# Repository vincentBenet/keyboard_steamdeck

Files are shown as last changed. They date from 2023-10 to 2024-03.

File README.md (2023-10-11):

# keyboard_steamdeck

[Github](https://github.com/vincentBenet/keyboard_steamdeck)
[Author: Vincent Bénet](https://github.com/vincentBenet)

## Introduction

This project aim to create a minimalist custom keyboard using standard keycaps.
The goal is to have no keys restriction compare to a 120% keyboard.

## Features
Bellow a list of features of this keyboard:

    - All keys from 120% keyboards (Directionnal arrows, del, backspace, G keys)
    
    - Possibility to switch from AZERTY to QWERTY
    
    - 8 programables macro-G-keys
    
    - Up to 6 differents keys mapped on one switch (FN1, FN2, FN3, FN4, SHIFT, Simple press)
    
    - Reprogramming possibility of firmware
    
    - Electro Static Protection using TVS USB
    
    - Very low energy consumption using STM32L0 Chip
    
    - Case-material versatile (Wood, Aluminium, Inox, plastic, ...) (2mm cutted sheet)
    
## Layout
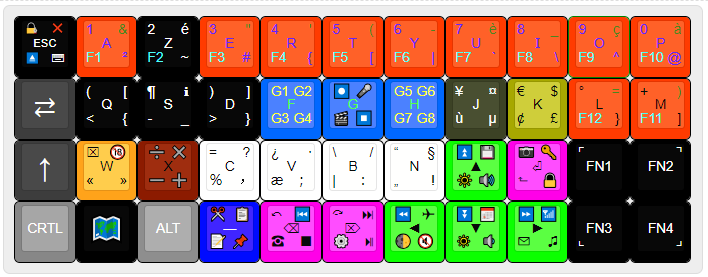
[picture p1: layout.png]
layout


[Edit - Layout](http://www.keyboard-layout-editor.com/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'%0A%7B%0A%0A%0A%0A%0A%0AR&=5%0AF5%0A(%0A%5B%0A%0A%0A%0A%0A%0AT&=6%0AF6%0A-%0A%7C%0A%0A%0A%0A%0A%0AY&=7%0AF7%0A%C3%A8%0A%60%0A%0A%0A%0A%0A%0AU&=8%0AF8%0A%2F_%0A%5C%0A%0A%0A%0A%0A%0A%E2%85%A0&=9%0AF9%0A%C3%A7%0A%5E%0A%0A%0A%0A%0A%0AO&=0%0AF10%0A%C3%A0%0A%2F@%0A%0A%0A%0A%0A%0AP%3B&@_c=%233d3d3d&t=%23ffffff&a:7&f:9%3B&=%E2%87%84&_c=%23000000&a:4&f:3%3B&=(%0A%3C%0A%5B%0A%7B%0A%0A%0A%0A%0A%0AQ&=%C2%B6%0A-%0A%E2%84%B9%EF%B8%8F%0A%2F_%0A%0A%0A%0A%0A%0AS&=)%0A%3E%0A%5D%0A%7D%0A%0A%0A%0A%0A%0AD&_c=%230068ff&t=%23fff300%0A%0A%0A%0A%0A%0A%0A%0A%0A%2300ff17%3B&=G1%0AG3%0AG2%0AG4%0A%0A%0A%0A%0A%0AF&_t=%23a32424%0A%0A%0A%23ff0000%0A%0A%0A%0A%0A%0A%2300ff17%3B&=%E2%8F%BA%0A%F0%9F%8E%AC%0A%F0%9F%8E%A4%0A%E2%8F%B9%0A%0A%0A%0A%0A%0AG&_t=%23fff300%0A%0A%0A%0A%0A%0A%0A%0A%0A%2300ff17%3B&=G5%0AG7%0AG6%0AG8%0A%0A%0A%0A%0A%0AH&_c=%233c4225&t=%23ffffff%3B&=%C2%A5%0A%C3%B9%0A%C2%A4%0A%C2%B5%0A%0A%0A%0A%0A%0AJ&_c=%23a7a800&t=%23000000%3B&=%E2%82%AC%0A%C2%A2%0A$%0A%C2%A3%0A%0A%0A%0A%0A%0AK&_c=%23ff3b00&t=%23000000%0A%2300ffde%0A%23337000%3B&=%C2%B0%0AF12%0A%2F=%0A%7D%0A%0A%0A%0A%0A%0AL&=+%0AF11%0A)%0A%5D%0A%0A%0A%0A%0A%0AM%3B&@_c=%233d3d3d&t=%23ffffff&a:7&f:9%3B&=%E2%86%91&_c=%23ffa31a&t=%23000000&a:4&f:3%3B&=%E2%8C%A7%0A%C2%AB%0A%F0%9F%94%9E%0A%C2%BB%0A%0A%0A%0A%0A%0AW&_c=%238c1b00%3B&=%E2%9E%97%0A%E2%9E%96%0A%E2%9C%96%EF%B8%8F%0A%E2%9E%95%0A%0A%0A%0A%0A%0AX&_c=%23ffffff%3B&=%2F=%0A%EF%BC%85%0A%3F%0A%EF%B9%90%0A%0A%0A%0A%0A%0AC&=%C2%BF%0A%C3%A6%0A%E2%80%A7%0A%EF%BC%9B%0A%0A%0A%0A%0A%0AV&=%5C%0A%7C%0A%2F%2F%0A%EF%BC%9A%0A%0A%0A%0A%0A%0AB&=%E2%80%9C%0A%E2%80%9E%0A%C2%A7%0A!%0A%0A%0A%0A%0A%0AN&_c=%230bff00%3B&=%E2%8F%AB%0A%F0%9F%94%86%0A%F0%9F%92%BE%0A%F0%9F%94%8A%0A%0A%0A%0A%0A%0A%E2%96%B2&_c=%23ff00e8%3B&=%F0%9F%93%B7%0A%E2%AC%91%0A%F0%9F%94%91%0A%F0%9F%94%92%0A%0A%0A%0A%0A%0A%E2%8F%8E&_c=%23000000&t=%23ffffff%3B&=%E2%8C%9C%0A%0A%0A%0A%0A%0A%0A%0A%0AFN1&=%0A%0A%E2%8C%9D%0A%0A%0A%0A%0A%0A%0AFN2%3B&@_c=%23878787&a:7%3B&=CRTL&_c=%23000000&f:9%3B&=%F0%9F%97%BA%EF%B8%8F&_c=%238e8e8e&f:3%3B&=ALT&_c=%23000bff&a:4%3B&=%E2%9C%82%EF%B8%8F%0A%F0%9F%93%9D%0A%F0%9F%93%8B%0A%F0%9F%93%8C%0A%0A%0A%0A%0A%0A%E2%80%95&_c=%23ff00e8&t=%23000000%3B&=%E2%A4%BA%0A%E2%98%8E%0A%E2%8F%AE%0A%E2%8F%B9%0A%0A%0A%0A%0A%0A%E2%8C%AB&=%E2%A4%BC%0A%E2%9A%99%EF%B8%8F%0A%E2%8F%AD%0A%E2%8F%AF%0A%0A%0A%0A%0A%0A%E2%8C%A6&_c=%230bff00%3B&=%E2%8F%AA%0A%F0%9F%8C%93%0A%E2%9C%88%0A%F0%9F%94%87%0A%0A%0A%0A%0A%0A%E2%97%84&=%E2%8F%AC%0A%F0%9F%94%85%0A%F0%9F%93%85%0A%F0%9F%94%89%0A%0A%0A%0A%0A%0A%E2%96%BC&=%E2%8F%A9%0A%E2%9C%89%0A%F0%9F%93%B6%0A%E2%99%AB%0A%0A%0A%0A%0A%0A%E2%96%BA&_c=%23000000&t=%23ffffff%3B&=%0A%E2%8C%9E%0A%0A%0A%0A%0A%0A%0A%0AFN3&=%0A%0A%0A%E2%8C%9F%0A%0A%0A%0A%0A%0AFN4)

## Model 3D
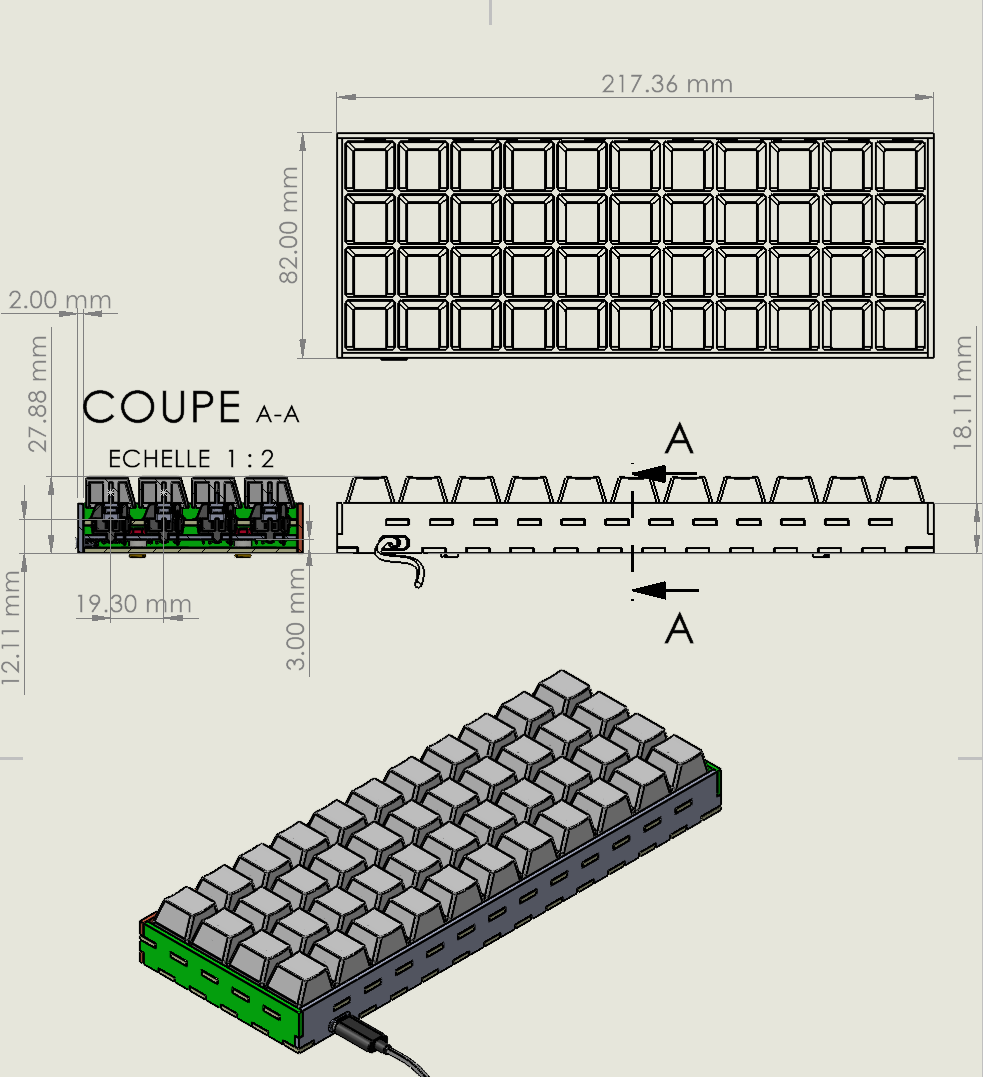
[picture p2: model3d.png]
model3d


## Schematic
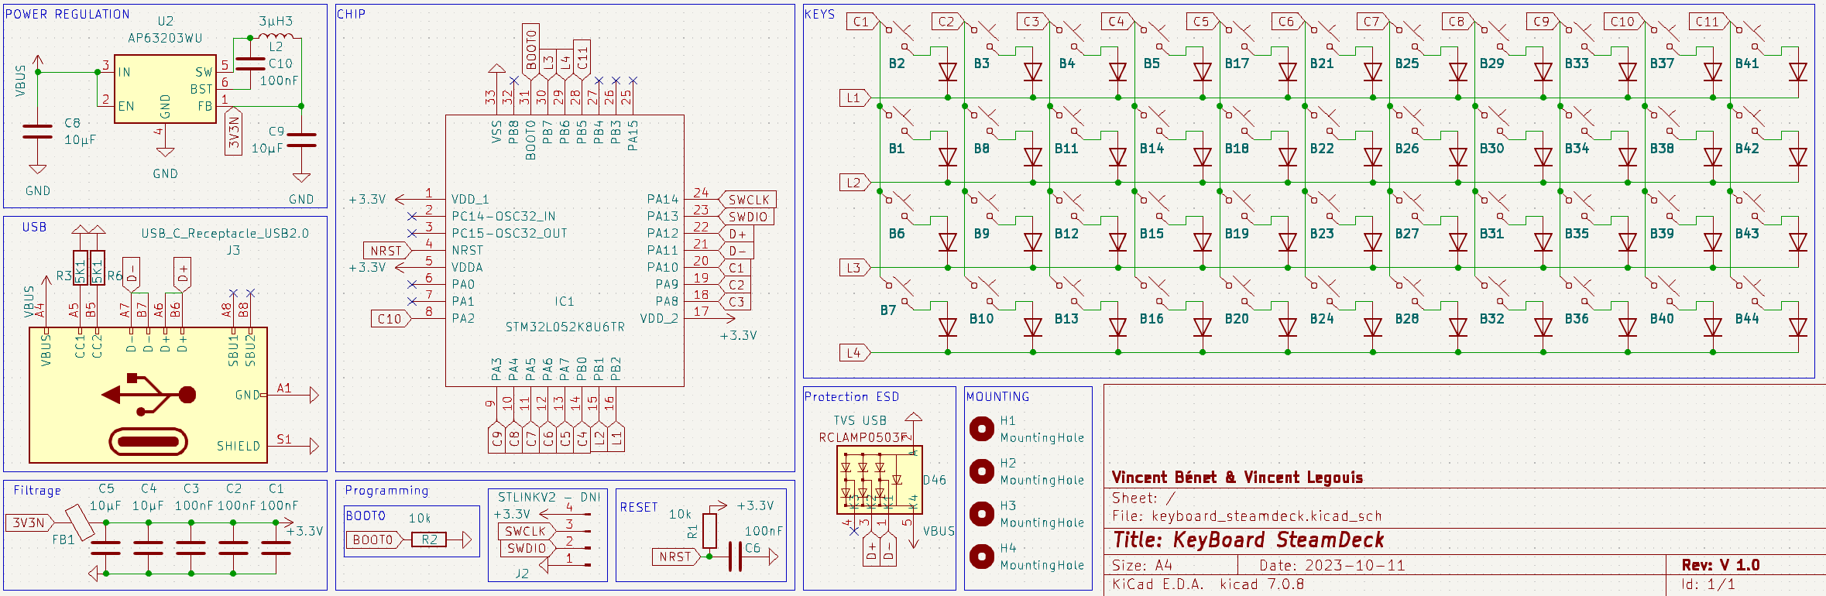
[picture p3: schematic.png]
schematic


## Routing
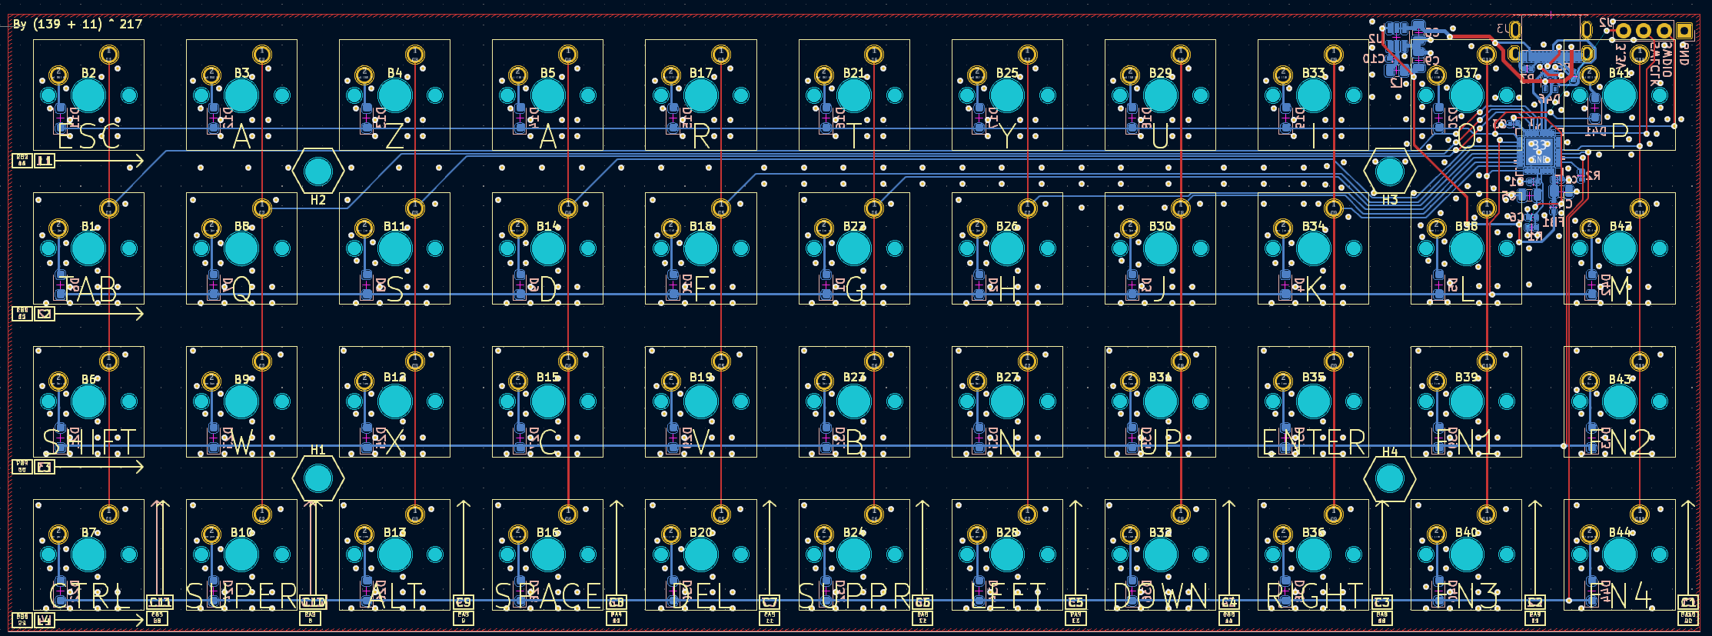
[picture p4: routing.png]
routing


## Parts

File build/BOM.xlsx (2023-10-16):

Item | Type | Domain | Name | Vendor | Price | Parameter | Quantity | URL | File
1 | Key switch | Mechatronic | Cherry MX Red | boutique-keycaps | 49.99 € | X | 47 | Cherry MX Red | Boutique Keycaps (boutique-keycaps.com) (https://boutique-keycaps.com/products/cherry-mx-red?variant=39810772959301) | X
2 | Keyboard case | Mechanic | plaque_arriere | Xometry | 147.60 € | Aluminium 2mm | 5 | https://xometry.eu/fr/ | build/plaque_arriere.DXF
3 |  |  | plaque_dessous |  |  |  | 5 |  | build/plaque_dessous.DXF
4 |  |  | plaque_frontale |  |  |  | 5 |  | build/plaque_frontale.DXF
5 |  |  | plaque_laterale |  |  |  | 10 |  | build/plaque_laterale.DXF
6 |  |  | plaque_principale |  |  |  | 5 |  | build/plaque_principale.DXF
7 | Keycaps | Mechanic | Keyboard layout |  |  |  | 1 |  | build/keyboard-layout.json (http://www.keyboard-layout-editor.com/)
8 | PCB | Electronic | PCB build | PCB ways | 213.01 € |  | 5 | https://www.pcbway.com/ | build/
9 | PCB Assembly | Electronic | PCB assembly service |  |  |  | 2 |  | X
10 | PCB componants | Electronic | Electronics componants |  |  |  | 2 |  | build/BOM_electronics.xlsx
 |  |  |  |  | 410.60 €

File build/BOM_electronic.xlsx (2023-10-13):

 |  |  | Keyboard SteamDeck - PCS BOM (Sample Bill of Materials)
Item # | *Designator | *Qty | Manufacturer | *Mfg Part # | Description / Value | *Package/Footprint | Type | Your Instructions / Notes
1 | > B1-B44 | 44 | cherrymx | MX2A-L1NN | CHERRY MX RED | X | thru-hole | Do Not Include
2 | > C1-C3, C6, C10 | 5 | YAGEO | CC0402KRX7R8BB104 | CAP CER 0.1UF 25V X7R 0402 | 402 | SMD
3 | > C4, C5, C8, C9 | 4 | Cal-Chip Electronics, Inc. | CAP0805 X7R 10UF 10% 16V | CAP CER 0.1UF 25V X7R 0402 | 805 | SMD
4 | > D1-D44 | 44 | Micro Commercial Co | 1N4148WX-TP | DIODE GEN PURP 75V 150MA SOD323 | SOD-323 | SMD
5 | D46 | 1 | Semtech Corporation | RCLAMP0503F.TCT | TVS DIODE 5VWM 25VC SC70-5 | SOT-353 | SMD
6 | FB1 | 1 | Pulse Electronics | PE-0603PFB121ST | FERRITE BEAD 600 OHM 0402 1LN | 402 | SMD
7 | > H1-H4 | 4 | X |  | M3 MOUNTING HOLE | X | thru-hole
8 | IC1 | 1 | StMicroelectronic | STM32L052K8U6TR | IC MCU 32BIT 64KB FLASH 32UFQFPN | SMD | SMD
9 | J2 | 1 | Würth Elektronik | 61300411121 | CONN HEADER VERT 4POS 2.54MM | 2.54 | thru-hole | Do Not Include
10 | J3 | 1 | Molex | 2130830005 | CONN RCP USB2.0 TYP C 24P SMD RA | Right Angle | thru-hole
11 | L2 | 1 | TDK Corporation | MLZ2012N3R3LT000 | FIXED IND 3.3UH 750MA 150MOHM SM | 805 | SMD
12 | > R1, R2 | 2 | Panasonic Electronic Components | ERA-2AEB103X | RES SMD 10K OHM 0.1% 1/16W 0402 | 402 | SMD
13 | > R3, R6 | 2 | KOA Speer Electronics, Inc. | RN73R1ETTP5101B25 | RES 5.1K OHM 0.1% 1/16W 0402 | 402 | SMD
14 | U2 | 1 | Diodes Incorporated | AP63203WU-7 | IC REG BUCK 3.3V 2A TSOT23-6 | SOT-23-6 | SMD
 |  | 62

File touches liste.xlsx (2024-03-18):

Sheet: KEYS
CODE | Name | Key | SHIFT | ALTGR | CTRL | MODIFIER | Usage key | Usage SHIFT | Usage ALTGR | Usage CTRL
01 | KEY_MOD_LCTRL | CTRL | __ | __ | __ | 1 | 5 | 0 | 0 | 0
02 | KEY_MOD_LSHIFT | SHIFT | __ | __ | __ | 1 | 5 | 0 | 0 | 0
04 | KEY_MOD_LALT | ALT | __ | __ | __ | 1 | 5 | 0 | 0 | 0
08 | KEY_MOD_LMETA | SUPER | __ | __ | __ | 1 | 5 | 0 | 0 | 0
10 | KEY_MOD_RCTRL | RCTRL | __ | __ | __ | 1 | 0 | 0 | 0 | 0
20 | KEY_MOD_RSHIFT | RSHIFT | __ | __ | __ | 1 | 0 | 0 | 0 | 0
40 | KEY_MOD_RALT | RALT | __ | __ | __ | 1 | 0 | 0 | 0 | 0
80 | KEY_MOD_RMETA | RMETA | __ | __ | __ | 1 | 0 | 0 | 0 | 0
00 | Reserved (no event indicated) | NONE | __ | __ | __ | 0 | 44 | 0 | 0 | 0
01 | Keyboard ErrorRollOver | __ | __ | __ | __ | 0 | 0 | 0 | 0 | 0
02 | Keyboard POSTFail | __ | __ | __ | __ | 0 | 0 | 0 | 0 | 0
03 | Keyboard ErrorUndefined | __ | __ | __ | __ | 0 | 0 | 0 | 0 | 0
04 | Keyboard a and A | q | __ | __ | __ | 0 | 1 | 0 | 0 | 0
05 | Keyboard b and B | b | __ | __ | __ | 0 | 1 | 0 | 0 | 0
06 | Keyboard c and C | c | __ | __ | COPY | 0 | 1 | 0 | 0 | 1
07 | Keyboard d and D | d | __ | __ | __ | 0 | 1 | 0 | 0 | 0
08 | Keyboard e and E | e | __ | € | __ | 0 | 1 | 0 | 1 | 0
09 | Keyboard f and F | f | __ | __ | FIND | 0 | 1 | 0 | 0 | 1
0A | Keyboard g and G | g | __ | __ | __ | 0 | 1 | 0 | 0 | 0
0B | Keyboard h and H | h | __ | __ | __ | 0 | 1 | 0 | 0 | 0
0C | Keyboard i and I | i | __ | __ | __ | 0 | 1 | 0 | 0 | 0
0D | Keyboard j and J | j | __ | __ | __ | 0 | 1 | 0 | 0 | 0
0E | Keyboard k and K | k | __ | __ | __ | 0 | 1 | 0 | 0 | 0
0F | Keyboard l and L | l | __ | __ | __ | 0 | 1 | 0 | 0 | 0
10 | Keyboard m and M | , | ? | __ | __ | 0 | 1 | 85 | 0 | 0
11 | Keyboard n and N | n | __ | __ | __ | 0 | 1 | 0 | 0 | 0
12 | Keyboard o and O | o | __ | __ | __ | 0 | 1 | 0 | 0 | 0
13 | Keyboard p and P | p | __ | __ | __ | 0 | 1 | 0 | 0 | 0
14 | Keyboard q and Q | a | __ | __ | __ | 0 | 1 | 0 | 0 | 0
15 | Keyboard r and R | r | __ | __ | REPLACE | 0 | 1 | 0 | 0 | 1
16 | Keyboard s and S | s | __ | __ | __ | 0 | 1 | 0 | 0 | 0
17 | Keyboard t and T | t | __ | __ | __ | 0 | 1 | 0 | 0 | 0
18 | Keyboard u and U | u | __ | __ | __ | 0 | 1 | 0 | 0 | 0
19 | Keyboard v and V | v | __ | __ | PASTE | 0 | 1 | 0 | 0 | 1
1A | Keyboard w and W | z | __ | __ | UNDO | 0 | 1 | 0 | 0 | 1
1B | Keyboard x and X | x | __ | __ | CUT | 0 | 1 | 0 | 0 | 1
1C | Keyboard y and Y | y | __ | __ | AGAIN | 0 | 1 | 0 | 0 | 1
1D | Keyboard z and Z | w | __ | __ | CLOSE | 0 | 1 | 0 | 0 | 1
1E | Keyboard 1 and ! | & | 1 | __ | __ | 0 | 2 | 1 | 0 | 0
1F | Keyboard 2 and @ | é | 2 | ~ | __ | 0 | 1 | 1 | 1 | 0
20 | Keyboard 3 and # | " | 3 | # | __ | 0 | 1 | 1 | 1 | 0
21 | Keyboard 4 and $ | ' | 4 | { | __ | 0 | 1 | 1 | 2 | 0
22 | Keyboard 5 and % | ( | 5 | [ | __ | 0 | 2 | 1 | 2 | 0
23 | Keyboard 6 and ^ | - | 6 | | | __ | 0 | 2 | 1 | 2 | 0
24 | Keyboard 7 and & | è | 7 | ` | __ | 0 | 1 | 1 | 1 | 0
25 | Keyboard 8 and * | _ | 8 | \ | __ | 0 | 2 | 1 | 2 | 0
26 | Keyboard 9 and ( | ç | 9 |  | __ | 0 | 1 | 1 | 1 | 0
27 | Keyboard 0 and ) | à | 0 | @ | __ | 0 | 1 | 1 | 1 | 0
28 | Keyboard Return (ENTER) | ENTER | __ | __ | __ | 0 | 1 | 0 | 0 | 0
29 | Keyboard ESCAPE | ESCAPE | __ | __ | __ | 0 | 1 | 0 | 0 | 0
2A | Keyboard DELETE (Backspace) | BACKSPACE | __ | __ | __ | 0 | 1 | 0 | 0 | 0
2B | Keyboard Tab | TAB | __ | __ | __ | 0 | 1 | 0 | 0 | 0
2C | Keyboard Spacebar | SPACE | __ | __ | __ | 0 | 1 | 0 | 0 | 0
2D | Keyboard - and (underscore) | ) | ° | ] | __ | 0 | 2 | 1 | 2 | 0
2E | Keyboard = and + | = | + | } | __ | 0 | 0 | 2 | 2 | 0
2F | Keyboard [ and { | ^ | ¨ | __ | __ | 0 | 2 | 1 | 0 | 0
30 | Keyboard ] and } | $ | £ | ¤ | __ | 0 | 1 | 1 | 1 | 0
31 | Keyboard \ and | | * | µ | __ | __ | 0 | 290 | 1 | 0 | 0
32 | Keyboard Non-US # and ~ | __ | __ | __ | __ | 0 | 0 | 0 | 0 | 0
33 | Keyboard ; and : | m | __ | __ | __ | 0 | 1 | 0 | 0 | 0
34 | Keyboard ‘ and “ | ù | % | __ | __ | 0 | 1 | 1 | 0 | 0
35 | Keyboard Grave Accent and Tilde | ² | __ | __ | __ | 0 | 1 | 0 | 0 | 0
36 | Keyboard, and < | ; | . | __ | __ | 0 | 1 | 1 | 0 | 0
37 | Keyboard . and > | : | / | __ | __ | 0 | 1 | 1 | 0 | 0
38 | Keyboard / and ? | ! | § | __ | __ | 0 | 1 | 1 | 0 | 0
39 | Keyboard Caps Lock | Caps Lock | __ | __ | __ | 0 | 1 | 0 | 0 | 0
3A | Keyboard F1 | F1 | __ | __ | __ | 0 | 1 | 0 | 0 | 0
3B | Keyboard F2 | F2 | __ | __ | __ | 0 | 1 | 0 | 0 | 0
3C | Keyboard F3 | F3 | __ | __ | __ | 0 | 1 | 0 | 0 | 0
3D | Keyboard F4 | F4 | __ | __ | __ | 0 | 1 | 0 | 0 | 0
3E | Keyboard F5 | F5 | __ | __ | __ | 0 | 1 | 0 | 0 | 0
3F | Keyboard F6 | F6 | __ | __ | __ | 0 | 1 | 0 | 0 | 0
40 | Keyboard F7 | F7 | __ | __ | __ | 0 | 1 | 0 | 0 | 0
41 | Keyboard F8 | F8 | __ | __ | __ | 0 | 1 | 0 | 0 | 0
42 | Keyboard F9 | F9 | __ | __ | __ | 0 | 1 | 0 | 0 | 0
43 | Keyboard F10 | F10 | __ | __ | __ | 0 | 1 | 0 | 0 | 0
44 | Keyboard F11 | F11 | __ | __ | __ | 0 | 1 | 0 | 0 | 0
45 | Keyboard F12 | F12 | __ | __ | __ | 0 | 1 | 0 | 0 | 0
46 | Keyboard PrintScreen | PRINTSCREEN | __ | __ | __ | 0 | 1 | 0 | 0 | 0
47 | Keyboard Scroll Lock | __ | __ | __ | __ | 0 | 0 | 0 | 0 | 0
48 | Keyboard Pause | PAUSE | __ | __ | __ | 0 | 1 | 0 | 0 | 0
49 | Keyboard Insert | INSERT | __ | __ | __ | 0 | 1 | 0 | 0 | 0
4A | Keyboard Home | BEGIN | __ | __ | __ | 0 | 1 | 0 | 0 | 0
4B | Keyboard PageUp | PAGE UP | __ | __ | __ | 0 | 1 | 0 | 0 | 0
4C | Keyboard Delete Forward | DELETE | __ | __ | __ | 0 | 1 | 0 | 0 | 0
4D | Keyboard End | END | __ | __ | __ | 0 | 1 | 0 | 0 | 0
4E | Keyboard PageDown | PAGE DOWN | __ | __ | __ | 0 | 1 | 0 | 0 | 0
4F | Keyboard RightArrow | RIGHT | __ | __ | __ | 0 | 1 | 0 | 0 | 0
50 | Keyboard LeftArrow | LEFT | __ | __ | __ | 0 | 1 | 0 | 0 | 0
51 | Keyboard DownArrow | DOWN | __ | __ | __ | 0 | 1 | 0 | 0 | 0
52 | Keyboard UpArrow | UP | __ | __ | __ | 0 | 1 | 0 | 0 | 0
53 | Keypad Num Lock and Clear | NUM LOCK | __ | __ | __ | 0 | 1 | 0 | 0 | 0
54 | Keypad / | __ | __ | __ | __ | 0 | 0 | 0 | 0 | 0
55 | Keypad * | __ | __ | __ | __ | 0 | 0 | 0 | 0 | 0
56 | Keypad - | __ | __ | __ | __ | 0 | 0 | 0 | 0 | 0
57 | Keypad + | __ | __ | __ | __ | 0 | 0 | 0 | 0 | 0
58 | Keypad ENTER | __ | __ | __ | __ | 0 | 0 | 0 | 0 | 0
59 | Keypad 1 and End | __ | __ | __ | __ | 0 | 0 | 0 | 0 | 0
5A | Keypad 2 and Down Arrow | __ | __ | __ | __ | 0 | 0 | 0 | 0 | 0
5B | Keypad 3 and PageDn | __ | __ | __ | __ | 0 | 0 | 0 | 0 | 0
5C | Keypad 4 and Left Arrow | __ | __ | __ | __ | 0 | 0 | 0 | 0 | 0
5D | Keypad 5 | __ | __ | __ | __ | 0 | 0 | 0 | 0 | 0
5E | Keypad 6 and Right Arrow | __ | __ | __ | __ | 0 | 0 | 0 | 0 | 0
5F | Keypad 7 and Home | __ | __ | __ | __ | 0 | 0 | 0 | 0 | 0
60 | Keypad 8 and Up Arrow | __ | __ | __ | __ | 0 | 0 | 0 | 0 | 0
61 | Keypad 9 and PageUp | __ | __ | __ | __ | 0 | 0 | 0 | 0 | 0
62 | Keypad 0 and Insert | __ | __ | __ | __ | 0 | 0 | 0 | 0 | 0
63 | Keypad . and Delete | __ | __ | __ | __ | 0 | 0 | 0 | 0 | 0
64 | Keyboard Non-US \ and | | < | > | __ | __ | 0 | 0 | 0 | 0 | 0
65 | Keyboard Application | APPS | __ | __ | __ | 0 | 1 | 0 | 0 | 0
66 | Keyboard Power | __ | __ | __ | __ | 0 | 0 | 0 | 0 | 0
67 | Keypad = | __ | __ | __ | __ | 0 | 0 | 0 | 0 | 0
68 | Keyboard F13 | __ | __ | __ | __ | 0 | 0 | 0 | 0 | 0
69 | Keyboard F14 | __ | __ | __ | __ | 0 | 0 | 0 | 0 | 0
6A | Keyboard F15 | __ | __ | __ | __ | 0 | 0 | 0 | 0 | 0
6B | Keyboard F16 | __ | __ | __ | __ | 0 | 0 | 0 | 0 | 0
6C | Keyboard F17 | __ | __ | __ | __ | 0 | 0 | 0 | 0 | 0
6D | Keyboard F18 | __ | __ | __ | __ | 0 | 0 | 0 | 0 | 0
6E | Keyboard F19 | __ | __ | __ | __ | 0 | 0 | 0 | 0 | 0
6F | Keyboard F20 | __ | __ | __ | __ | 0 | 0 | 0 | 0 | 0
70 | Keyboard F21 | __ | __ | __ | __ | 0 | 0 | 0 | 0 | 0
71 | Keyboard F22 | __ | __ | __ | __ | 0 | 0 | 0 | 0 | 0
72 | Keyboard F23 | __ | __ | __ | __ | 0 | 0 | 0 | 0 | 0
73 | Keyboard F24 | __ | __ | __ | __ | 0 | 0 | 0 | 0 | 0
74 | Keyboard Execute | __ | __ | __ | __ | 0 | 0 | 0 | 0 | 0
75 | Keyboard Help | __ | __ | __ | __ | 0 | 0 | 0 | 0 | 0
76 | Keyboard Menu | __ | __ | __ | __ | 0 | 0 | 0 | 0 | 0
77 | Keyboard Select | __ | __ | __ | __ | 0 | 0 | 0 | 0 | 0
78 | Keyboard Stop | __ | __ | __ | __ | 0 | 0 | 0 | 0 | 0
79 | Keyboard Again | __ | __ | __ | __ | 0 | 0 | 0 | 0 | 0
7A | Keyboard Undo | __ | __ | __ | __ | 0 | 0 | 0 | 0 | 0
7B | Keyboard Cut | __ | __ | __ | __ | 0 | 0 | 0 | 0 | 0
7C | Keyboard Copy | __ | __ | __ | __ | 0 | 0 | 0 | 0 | 0
7D | Keyboard Paste | __ | __ | __ | __ | 0 | 0 | 0 | 0 | 0
7E | Keyboard Find | __ | __ | __ | __ | 0 | 0 | 0 | 0 | 0
7F | Keyboard Mute | __ | __ | __ | __ | 0 | 0 | 0 | 0 | 0
80 | Keyboard Volume Up | __ | __ | __ | __ | 0 | 0 | 0 | 0 | 0
81 | Keyboard Volume Down | __ | __ | __ | __ | 0 | 0 | 0 | 0 | 0
82 | Keyboard Locking Caps Lock | __ | __ | __ | __ | 0 | 0 | 0 | 0 | 0
83 | Keyboard Locking Num Lock | __ | __ | __ | __ | 0 | 0 | 0 | 0 | 0
84 | Keyboard Locking Scroll Lock | __ | __ | __ | __ | 0 | 0 | 0 | 0 | 0
85 | Keypad Comma | __ | __ | __ | __ | 0 | 0 | 0 | 0 | 0
86 | Keypad Equal Sign | __ | __ | __ | __ | 0 | 0 | 0 | 0 | 0
87 | KEY_RO | RO | __ | __ | __ | 0 | 1 | 0 | 0 | 0
88 | KEY_KATAKANAHIRAGANA | __ | __ | __ | __ | 0 | 0 | 0 | 0 | 0
89 | KEY_YEN | __ | __ | __ | __ | 0 | 0 | 0 | 0 | 0
8A | KEY_HENKAN | __ | __ | __ | __ | 0 | 0 | 0 | 0 | 0
8B | KEY_MUHENKAN | __ | __ | __ | __ | 0 | 0 | 0 | 0 | 0
8C | KEY_KPJPCOMMA | __ | __ | __ | __ | 0 | 0 | 0 | 0 | 0
8D | Keyboard International7 | __ | __ | __ | __ | 0 | 0 | 0 | 0 | 0
8E | Keyboard International8 | __ | __ | __ | __ | 0 | 0 | 0 | 0 | 0
8F | Keyboard International9 | __ | __ | __ | __ | 0 | 0 | 0 | 0 | 0
90 | KEY_HANGEUL | __ | __ | __ | __ | 0 | 0 | 0 | 0 | 0
91 | KEY_HANJA | __ | __ | __ | __ | 0 | 0 | 0 | 0 | 0
92 | KEY_KATAKANA | __ | __ | __ | __ | 0 | 0 | 0 | 0 | 0
93 | KEY_HIRAGANA | __ | __ | __ | __ | 0 | 0 | 0 | 0 | 0
94 | KEY_ZENKAKUHANKAKU | __ | __ | __ | __ | 0 | 0 | 0 | 0 | 0
95 | Keyboard LANG6 | __ | __ | __ | __ | 0 | 0 | 0 | 0 | 0
96 | Keyboard LANG7 | __ | __ | __ | __ | 0 | 0 | 0 | 0 | 0
97 | Keyboard LANG8 | __ | __ | __ | __ | 0 | 0 | 0 | 0 | 0
98 | Keyboard LANG9 | __ | __ | __ | __ | 0 | 0 | 0 | 0 | 0
99 | Keyboard Alternate Erase | __ | __ | __ | __ | 0 | 0 | 0 | 0 | 0
9A | Keyboard SysReq/Attention | __ | __ | __ | __ | 0 | 0 | 0 | 0 | 0
9B | Keyboard Cancel | __ | __ | __ | __ | 0 | 0 | 0 | 0 | 0
9C | Keyboard Clear | __ | __ | __ | __ | 0 | 0 | 0 | 0 | 0
9D | Keyboard Prior | __ | __ | __ | __ | 0 | 0 | 0 | 0 | 0
9E | Keyboard Return | __ | __ | __ | __ | 0 | 0 | 0 | 0 | 0
9F | Keyboard Separator | __ | __ | __ | __ | 0 | 0 | 0 | 0 | 0
A0 | Keyboard Out | __ | __ | __ | __ | 0 | 0 | 0 | 0 | 0
A1 | Keyboard Oper | __ | __ | __ | __ | 0 | 0 | 0 | 0 | 0
A2 | Keyboard Clear/Again | __ | __ | __ | __ | 0 | 0 | 0 | 0 | 0
A3 | Keyboard CrSel/Props | __ | __ | __ | __ | 0 | 0 | 0 | 0 | 0
A4 | Keyboard ExSel | __ | __ | __ | __ | 0 | 0 | 0 | 0 | 0
A5 | Reserved | __ | __ | __ | __ | 0 | 0 | 0 | 0 | 0
B0 | Keypad 00 | __ | __ | __ | __ | 0 | 0 | 0 | 0 | 0
B1 | Keypad 000 | __ | __ | __ | __ | 0 | 0 | 0 | 0 | 0
B2 | Thousands Separator | __ | __ | __ | __ | 0 | 0 | 0 | 0 | 0
B3 | Decimal Separator | __ | __ | __ | __ | 0 | 0 | 0 | 0 | 0
B4 | Currency Unit | __ | __ | __ | __ | 0 | 0 | 0 | 0 | 0
B5 | Currency Sub-unit | __ | __ | __ | __ | 0 | 0 | 0 | 0 | 0
B6 | Keypad ( | __ | __ | __ | __ | 0 | 0 | 0 | 0 | 0
B7 | Keypad ) | __ | __ | __ | __ | 0 | 0 | 0 | 0 | 0
B8 | Keypad { | __ | __ | __ | __ | 0 | 0 | 0 | 0 | 0
B9 | Keypad } | __ | __ | __ | __ | 0 | 0 | 0 | 0 | 0
BA | Keypad Tab | __ | __ | __ | __ | 0 | 0 | 0 | 0 | 0
BB | Keypad Backspace | __ | __ | __ | __ | 0 | 0 | 0 | 0 | 0
BC | Keypad A | __ | __ | __ | __ | 0 | 0 | 0 | 0 | 0
BD | Keypad B | __ | __ | __ | __ | 0 | 0 | 0 | 0 | 0
BE | Keypad C | __ | __ | __ | __ | 0 | 0 | 0 | 0 | 0
BF | Keypad D | __ | __ | __ | __ | 0 | 0 | 0 | 0 | 0
C0 | Keypad E | __ | __ | __ | __ | 0 | 0 | 0 | 0 | 0
C1 | Keypad F | __ | __ | __ | __ | 0 | 0 | 0 | 0 | 0
C2 | Keypad XOR | __ | __ | __ | __ | 0 | 0 | 0 | 0 | 0
C3 | Keypad ^ | __ | __ | __ | __ | 0 | 0 | 0 | 0 | 0
C4 | Keypad % | __ | __ | __ | __ | 0 | 0 | 0 | 0 | 0
C5 | Keypad < | __ | __ | __ | __ | 0 | 0 | 0 | 0 | 0
C6 | Keypad > | __ | __ | __ | __ | 0 | 0 | 0 | 0 | 0
C7 | Keypad & | __ | __ | __ | __ | 0 | 0 | 0 | 0 | 0
C8 | Keypad && | __ | __ | __ | __ | 0 | 0 | 0 | 0 | 0
C9 | Keypad | | __ | __ | __ | __ | 0 | 0 | 0 | 0 | 0
CA | Keypad || | __ | __ | __ | __ | 0 | 0 | 0 | 0 | 0
CB | Keypad : | __ | __ | __ | __ | 0 | 0 | 0 | 0 | 0
CC | Keypad # | __ | __ | __ | __ | 0 | 0 | 0 | 0 | 0
CD | Keypad Space | __ | __ | __ | __ | 0 | 0 | 0 | 0 | 0
CE | Keypad @ | __ | __ | __ | __ | 0 | 0 | 0 | 0 | 0
CF | Keypad ! | __ | __ | __ | __ | 0 | 0 | 0 | 0 | 0
D0 | Keypad Memory Store | __ | __ | __ | __ | 0 | 0 | 0 | 0 | 0
D1 | Keypad Memory Recall | __ | __ | __ | __ | 0 | 0 | 0 | 0 | 0
D2 | Keypad Memory Clear | __ | __ | __ | __ | 0 | 0 | 0 | 0 | 0
D3 | Keypad Memory Add | __ | __ | __ | __ | 0 | 0 | 0 | 0 | 0
D4 | Keypad Memory Subtract | __ | __ | __ | __ | 0 | 0 | 0 | 0 | 0
D5 | Keypad Memory Multiply | __ | __ | __ | __ | 0 | 0 | 0 | 0 | 0
D6 | Keypad Memory Divide | __ | __ | __ | __ | 0 | 0 | 0 | 0 | 0
D7 | Keypad +/- | __ | __ | __ | __ | 0 | 0 | 0 | 0 | 0
D8 | Keypad Clear | __ | __ | __ | __ | 0 | 0 | 0 | 0 | 0
D9 | Keypad Clear Entry | __ | __ | __ | __ | 0 | 0 | 0 | 0 | 0
DA | Keypad Binary | __ | __ | __ | __ | 0 | 0 | 0 | 0 | 0
DB | Keypad Octal | __ | __ | __ | __ | 0 | 0 | 0 | 0 | 0
DC | Keypad Decimal | __ | __ | __ | __ | 0 | 0 | 0 | 0 | 0
DD | Keypad Hexadecimal | __ | __ | __ | __ | 0 | 0 | 0 | 0 | 0
DE | Reserved | __ | __ | __ | __ | 0 | 0 | 0 | 0 | 0
DF | Reserved | __ | __ | __ | __ | 0 | 0 | 0 | 0 | 0
E0 | KEY_LEFTCTRL | __ | __ | __ | __ | 0 | 0 | 0 | 0 | 0
E1 | KEY_LEFTSHIFT | __ | __ | __ | __ | 0 | 0 | 0 | 0 | 0
E2 | KEY_LEFTALT | __ | __ | __ | __ | 0 | 0 | 0 | 0 | 0
E3 | KEY_LEFTMETA | __ | __ | __ | __ | 0 | 0 | 0 | 0 | 0
E4 | KEY_RIGHTCTRL | __ | __ | __ | __ | 0 | 0 | 0 | 0 | 0
E5 | KEY_RIGHTSHIFT | __ | __ | __ | __ | 0 | 0 | 0 | 0 | 0
E6 | KEY_RIGHTALT | __ | __ | __ | __ | 0 | 0 | 0 | 0 | 0
E7 | KEY_RIGHTMETA | __ | __ | __ | __ | 0 | 0 | 0 | 0 | 0
E8 | KEY_MEDIA_PLAYPAUSE | __ | __ | __ | __ | 0 | 0 | 0 | 0 | 0
E9 | KEY_MEDIA_STOPCD | __ | __ | __ | __ | 0 | 0 | 0 | 0 | 0
EA | KEY_MEDIA_PREVIOUSSONG | __ | __ | __ | __ | 0 | 0 | 0 | 0 | 0
EB | KEY_MEDIA_NEXTSONG | __ | __ | __ | __ | 0 | 0 | 0 | 0 | 0
EC | KEY_MEDIA_EJECTCD | __ | __ | __ | __ | 0 | 0 | 0 | 0 | 0
ED | KEY_MEDIA_VOLUMEUP | __ | __ | __ | __ | 0 | 0 | 0 | 0 | 0
EE | KEY_MEDIA_VOLUMEDOWN | __ | __ | __ | __ | 0 | 0 | 0 | 0 | 0
EF | KEY_MEDIA_MUTE | __ | __ | __ | __ | 0 | 0 | 0 | 0 | 0
F0 | KEY_MEDIA_WWW | __ | __ | __ | __ | 0 | 0 | 0 | 0 | 0
F1 | KEY_MEDIA_BACK | __ | __ | __ | __ | 0 | 0 | 0 | 0 | 0
F2 | KEY_MEDIA_FORWARD | __ | __ | __ | __ | 0 | 0 | 0 | 0 | 0
F3 | KEY_MEDIA_STOP | __ | __ | __ | __ | 0 | 0 | 0 | 0 | 0
F4 | KEY_MEDIA_FIND | __ | __ | __ | __ | 0 | 0 | 0 | 0 | 0
F5 | KEY_MEDIA_SCROLLUP | __ | __ | __ | __ | 0 | 0 | 0 | 0 | 0
F6 | KEY_MEDIA_SCROLLDOWN | __ | __ | __ | __ | 0 | 0 | 0 | 0 | 0
F7 | KEY_MEDIA_EDIT | __ | __ | __ | __ | 0 | 0 | 0 | 0 | 0
F8 | KEY_MEDIA_SLEEP | __ | __ | __ | __ | 0 | 0 | 0 | 0 | 0
F9 | KEY_MEDIA_COFFEE | __ | __ | __ | __ | 0 | 0 | 0 | 0 | 0
FA | KEY_MEDIA_REFRESH | __ | __ | __ | __ | 0 | 0 | 0 | 0 | 0
FB | KEY_MEDIA_CALC | __ | __ | __ | __ | 0 | 0 | 0 | 0 | 0
FC | FN1 | FN1 | __ | __ | __ | 0 | 5 | 0 | 0 | 0
FD | FN2 | FN2 | __ | __ | __ | 0 | 5 | 0 | 0 | 0
FE | FN3 | FN3 | __ | __ | __ | 0 | 5 | 0 | 0 | 0
FF | FN4 | FN4 | __ | __ | __ | 0 | 5 | 0 | 0 | 0

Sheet: LAYERS
KEYS | c1 | c2 | c3 | c4 | c5 | c6 | c7 | c8 | c9 | c10 | c11 | INPUTKEYS | 1 | 2 | 3 | 4 | 5 | 6 | 7 | 8 | 9 | 10 | 11 | KEY-shift | 1 | 2 | 3 | 4 | 5 | 6 | 7 | 8 | 9 | 10 | 11 | Key-altgr | 1 | 2 | 3 | 4 | 5 | 6 | 7 | 8 | 9 | 10 | 11 | Key-ctrl | 1 | 2 | 3 | 4 | 5 | 6 | 7
l1 | ESCAPE | a | z | e | r | t | y | u | i | o | p | 1 | 0x29 | 0x14 | 0x1A | 0x08 | 0x15 | 0x17 | 0x1C | 0x18 | 0x0C | 0x12 | 0x13 | 1 | 0 | 0 | 0 | 0 | 0 | 0 | 0 | 0 | 0 | 0 | 0 | 1 | 0 | 0 | 0 | 0 | 0 | 0 | 0 | 0 | 0 | 0 | 0 | 1 | 0 | 0 | 0 | 0 | 0 | 0 | 0
l2 | TAB | q | s | d | f | g | h | j | k | l | m | 2 | 0x2B | 0x04 | 0x16 | 0x07 | 0x09 | 0x0A | 0x0B | 0x0D | 0x0E | 0x0F | 0x33 | 2 | 0 | 0 | 0 | 0 | 0 | 0 | 0 | 0 | 0 | 0 | 0 | 2 | 0 | 0 | 0 | 0 | 0 | 0 | 0 | 0 | 0 | 0 | 0 | 2 | 0 | 0 | 0 | 0 | 0 | 0 | 0
l3 | SHIFT | w | x | c | v | b | n | UP | ENTER | FN1 | FN2 | 3 | 0x02 | 0x1D | 0x1B | 0x06 | 0x19 | 0x05 | 0x11 | 0x52 | 0x28 | 0xFC | 0xFD | 3 | 0 | 0 | 0 | 0 | 0 | 0 | 0 | 0 | 0 | 0 | 0 | 3 | 0 | 0 | 0 | 0 | 0 | 0 | 0 | 0 | 0 | 0 | 0 | 3 | 0 | 0 | 0 | 0 | 0 | 0 | 0
l4 | CTRL | SUPER | ALT | BACKSPACE | SPACE | DELETE | LEFT | DOWN | RIGHT | FN3 | FN4 | 4 | 0x01 | 0x08 | 0x04 | 0x2A | 0x2C | 0x4C | 0x50 | 0x51 | 0x4F | 0xFE | 0xFF | 4 | 0 | 0 | 0 | 0 | 0 | 0 | 0 | 0 | 0 | 0 | 0 | 4 | 0 | 0 | 0 | 0 | 0 | 0 | 0 | 0 | 0 | 0 | 0 | 4 | 0 | 0 | 0 | 0 | 0 | 0 | 0
FN1_ | c1 | c2 | c3 | c4 | c5 | c6 | c7 | c8 | c9 | c10 | c11 | FN1KEYS | 1 | 2 | 3 | 4 | 5 | 6 | 7 | 8 | 9 | 10 | 11 | FN1-shift | 1 | 2 | 3 | 4 | 5 | 6 | 7 | 8 | 9 | 10 | 11 | FN1-altgr | 1 | 2 | 3 | 4 | 5 | 6 | 7 | 8 | 9 | 10 | 11 | FN1-ctrl | 1 | 2 | 3 | 4 | 5 | 6 | 7
l1 | NONE | & | é | " | ' | ( | - | è | _ | ç | à | 1 | 0x00 | 0x1E | 0x1F | 0x20 | 0x21 | 0x22 | 0x23 | 0x24 | 0x25 | 0x26 | 0x27 | 1 | 0 | 0 | 0 | 0 | 0 | 0 | 0 | 0 | 0 | 0 | 0 | 1 | 0 | 0 | 0 | 0 | 0 | 0 | 0 | 0 | 0 | 0 | 0 | 1 | 0 | 0 | 0 | 0 | 0 | 0 | 0
l2 | CAPS LOCK | ( | ^ | ) | , | ; | ? | ù | NONE | ) | = | 2 | 0x39 | 0x22 | 0x2F | 0x2D | 0x10 | 0x36 | 0x10 | 0x34 | 0x00 | 0x2D | 0x2E | 2 | 0 | 0 | 0 | 0 | 0 | 0 | 1 | 0 | 0 | 0 | 0 | 2 | 0 | 0 | 0 | 0 | 0 | 0 | 0 | 0 | 0 | 0 | 0 | 2 | 0 | 0 | 0 | 0 | 0 | 0 | 0
l3 | SHIFT | { | ¨ | } | . | : | ! | COPY | PASTE | FN1 | FN2 | 3 | 0x02 | 0x21 | 0x2F | 0x2E | 0x36 | 0x37 | 0x38 | 0x06 | 0x19 | 0xFC | 0xFD | 3 | 0 | 0 | 1 | 0 | 1 | 0 | 0 | 0 | 0 | 0 | 0 | 3 | 0 | 1 | 0 | 1 | 0 | 0 | 0 | 0 | 0 | 0 | 0 | 3 | 0 | 0 | 0 | 0 | 0 | 0 | 0
l4 | CTRL | SUPER | ALT | NONE | PAUSE | NONE | NONE | CUT | PRINTSCREEN | FN3 | FN4 | 4 | 0x01 | 0x08 | 0x04 | 0x00 | 0x48 | 0x00 | 0x00 | 0x1B | 0x46 | 0xFE | 0xFF | 4 | 0 | 0 | 0 | 0 | 0 | 0 | 0 | 0 | 0 | 0 | 0 | 4 | 0 | 0 | 0 | 0 | 0 | 0 | 0 | 0 | 0 | 0 | 0 | 4 | 0 | 0 | 0 | 0 | 0 | 0 | 0
FN2_ | c1 | c2 | c3 | c4 | c5 | c6 | c7 | c8 | c9 | c10 | c11 | FN2KEYS | 1 | 2 | 3 | 4 | 5 | 6 | 7 | 8 | 9 | 10 | 11 | FN2-shift | 1 | 2 | 3 | 4 | 5 | 6 | 7 | 8 | 9 | 10 | 11 | FN2-altgr | 1 | 2 | 3 | 4 | 5 | 6 | 7 | 8 | 9 | 10 | 11 | FN2-ctrl | 1 | 2 | 3 | 4 | 5 | 6 | 7
l1 | NONE | 1 | 2 | 3 | 4 | 5 | 6 | 7 | 8 | 9 | 0 | 1 | 0x00 | 0x1E | 0x1F | 0x20 | 0x21 | 0x22 | 0x23 | 0x24 | 0x25 | 0x26 | 0x27 | 1 | 0 | 1 | 1 | 1 | 1 | 1 | 1 | 1 | 1 | 1 | 1 | 1 | 0 | 0 | 0 | 0 | 0 | 0 | 0 | 0 | 0 | 0 | 0 | 1 | 0 | 0 | 0 | 0 | 0 | 0 | 0
l2 | NUM LOCK | < | / | > | - | = | + | * | % | ° | + | 2 | 0x53 | 0x64 | 0x37 | 0x64 | 0x23 | 0x2E | 0x2E | 0x31 | 0x34 | 0x2D | 0x2E | 2 | 0 | 0 | 1 | 1 | 0 | 0 | 1 | 0 | 1 | 1 | 1 | 2 | 0 | 0 | 0 | 0 | 0 | 0 | 0 | 0 | 0 | 0 | 0 | 2 | 0 | 0 | 0 | 0 | 0 | 0 | 0
l3 | SHIFT | [ | \ | ] | & | | | _ | FIND | NONE | FN1 | FN2 | 3 | 0x02 | 0x22 | 0x25 | 0x2D | 0x1E | 0x23 | 0x25 | 0x09 | 0x00 | 0xFC | 0xFD | 3 | 0 | 0 | 0 | 0 | 0 | 0 | 0 | 0 | 0 | 0 | 0 | 3 | 0 | 1 | 1 | 1 | 0 | 1 | 0 | 0 | 0 | 0 | 0 | 3 | 0 | 0 | 0 | 0 | 0 | 0 | 0
l4 | CTRL | SUPER | ALT | NONE | NONE | CLOSE | UNDO | REPLACE | AGAIN | FN3 | FN4 | 4 | 0x01 | 0x08 | 0x04 | 0x00 | 0x00 | 0x1D | 0x1A | 0x15 | 0x1C | 0xFE | 0xFF | 4 | 0 | 0 | 0 | 0 | 0 | 0 | 0 | 0 | 0 | 0 | 0 | 4 | 0 | 0 | 0 | 0 | 0 | 0 | 0 | 0 | 0 | 0 | 0 | 4 | 0 | 0 | 0 | 0 | 0 | 1 | 1
FN3_ | c1 | c2 | c3 | c4 | c5 | c6 | c7 | c8 | c9 | c10 | c11 | FN3KEYS | 1 | 2 | 3 | 4 | 5 | 6 | 7 | 8 | 9 | 10 | 11 | FN3-shift | 1 | 2 | 3 | 4 | 5 | 6 | 7 | 8 | 9 | 10 | 11 | FN3-altgr | 1 | 2 | 3 | 4 | 5 | 6 | 7 | 8 | 9 | 10 | 11 | FN3-ctrl | 1 | 2 | 3 | 4 | 5 | 6 | 7
l1 | NONE | F1 | F2 | F3 | F4 | F5 | F6 | F7 | F8 | F9 | F10 | 1 | 0x00 | 0x3A | 0x3B | 0x3C | 0x3D | 0x3E | 0x3F | 0x40 | 0x41 | 0x42 | 0x43 | 1 | 0 | 0 | 0 | 0 | 0 | 0 | 0 | 0 | 0 | 0 | 0 | 1 | 0 | 0 | 0 | 0 | 0 | 0 | 0 | 0 | 0 | 0 | 0 | 1 | 0 | 0 | 0 | 0 | 0 | 0 | 0
l2 | INSERT | NONE | NONE | NONE | NONE | NONE | NONE | NONE | NONE | F11 | F12 | 2 | 0x49 | 0x00 | 0x00 | 0x00 | 0x00 | 0x00 | 0x00 | 0x00 | 0x00 | 0x44 | 0x45 | 2 | 0 | 0 | 0 | 0 | 0 | 0 | 0 | 0 | 0 | 0 | 0 | 2 | 0 | 0 | 0 | 0 | 0 | 0 | 0 | 0 | 0 | 0 | 0 | 2 | 0 | 0 | 0 | 0 | 0 | 0 | 0
l3 | SHIFT | NONE | NONE | NONE | NONE | NONE | NONE | NONE | NONE | FN1 | FN2 | 3 | 0x02 | 0x00 | 0x00 | 0x00 | 0x00 | 0x00 | 0x00 | 0x00 | 0x00 | 0xFC | 0xFD | 3 | 0 | 0 | 0 | 0 | 0 | 0 | 0 | 0 | 0 | 0 | 0 | 3 | 0 | 0 | 0 | 0 | 0 | 0 | 0 | 0 | 0 | 0 | 0 | 3 | 0 | 0 | 0 | 0 | 0 | 0 | 0
l4 | CTRL | SUPER | ALT | NONE | NONE | NONE | NONE | NONE | NONE | FN3 | FN4 | 4 | 0x01 | 0x08 | 0x04 | 0x00 | 0x00 | 0x00 | 0x00 | 0x00 | 0x00 | 0xFE | 0xFF | 4 | 0 | 0 | 0 | 0 | 0 | 0 | 0 | 0 | 0 | 0 | 0 | 4 | 0 | 0 | 0 | 0 | 0 | 0 | 0 | 0 | 0 | 0 | 0 | 4 | 0 | 0 | 0 | 0 | 0 | 0 | 0
FN4_ | c1 | c2 | c3 | c4 | c5 | c6 | c7 | c8 | c9 | c10 | c11 | FN4KEYS | 1 | 2 | 3 | 4 | 5 | 6 | 7 | 8 | 9 | 10 | 11 | FN4-shift | 1 | 2 | 3 | 4 | 5 | 6 | 7 | 8 | 9 | 10 | 11 | FN4-altgr | 1 | 2 | 3 | 4 | 5 | 6 | 7 | 8 | 9 | 10 | 11 | FN4-ctrl | 1 | 2 | 3 | 4 | 5 | 6 | 7
l1 | NONE | ² | ~ | # | { | [ | | | ` | \ | ^ | @ | 1 | 0x00 | 0x35 | 0x1F | 0x20 | 0x21 | 0x22 | 0x23 | 0x24 | 0x25 | 0x2F | 0x27 | 1 | 0 | 0 | 0 | 0 | 0 | 0 | 0 | 0 | 0 | 0 | 0 | 1 | 0 | 0 | 1 | 1 | 1 | 1 | 1 | 1 | 1 | 0 | 1 | 1 | 0 | 0 | 0 | 0 | 0 | 0 | 0
l2 | NONE | NONE | NONE | NONE | $ | € | § | £ | ¤ | ] | } | 2 | 0x00 | 0x00 | 0x00 | 0x00 | 0x30 | 0x08 | 0x38 | 0x30 | 0x30 | 0x2D | 0x2E | 2 | 0 | 0 | 0 | 0 | 0 | 0 | 1 | 1 | 0 | 0 | 0 | 2 | 0 | 0 | 0 | 0 | 0 | 1 | 0 | 0 | 1 | 1 | 1 | 2 | 0 | 0 | 0 | 0 | 0 | 0 | 0
l3 | SHIFT | NONE | NONE | NONE | NONE | RO | µ | PAGE UP | APPS | FN1 | FN2 | 3 | 0x02 | 0x00 | 0x00 | 0x00 | 0x00 | 0x87 | 0x31 | 0x4B | 0x65 | 0xFC | 0xFD | 3 | 0 | 0 | 0 | 0 | 0 | 0 | 1 | 0 | 0 | 0 | 0 | 3 | 0 | 0 | 0 | 0 | 0 | 0 | 0 | 0 | 0 | 0 | 0 | 3 | 0 | 0 | 0 | 0 | 0 | 0 | 0
l4 | CTRL | SUPER | ALT | NONE | NONE | NONE | BEGIN | PAGE DOWN | END | FN3 | FN4 | 4 | 0x01 | 0x08 | 0x04 | 0x00 | 0x00 | 0x00 | 0x4A | 0x4E | 0x4D | 0xFE | 0xFF | 4 | 0 | 0 | 0 | 0 | 0 | 0 | 0 | 0 | 0 | 0 | 0 | 4 | 0 | 0 | 0 | 0 | 0 | 0 | 0 | 0 | 0 | 0 | 0 | 4 | 0 | 0 | 0 | 0 | 0 | 0 | 0

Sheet: OUTPUT
INPUTKEYS | 1 | 2 | 3 | 4 | 5 | 6 | 7 | 8 | 9 | 10 | 11
1 | 0x29, | 0x14, | 0x1A, | 0x08, | 0x15, | 0x17, | 0x1C, | 0x18, | 0x0C, | 0x12, | 0x13,
2 | 0x2B, | 0x04, | 0x16, | 0x07, | 0x09, | 0x0A, | 0x0B, | 0x0D, | 0x0E, | 0x0F, | 0x33,
3 | 0x02, | 0x1D, | 0x1B, | 0x06, | 0x19, | 0x05, | 0x11, | 0x52, | 0x28, | 0xFC, | 0xFD,
4 | 0x01, | 0x08, | 0x04, | 0x2A, | 0x2C, | 0x4C, | 0x50, | 0x51, | 0x4F, | 0xFE, | 0xFF
FN1KEYS | 1 | 2 | 3 | 4 | 5 | 6 | 7 | 8 | 9 | 10 | 11
1 | 0x00, | 0x1E, | 0x1F, | 0x20, | 0x21, | 0x22, | 0x23, | 0x24, | 0x25, | 0x26, | 0x27,
2 | 0x39, | 0x22, | 0x2F, | 0x2D, | 0x10, | 0x36, | 0x10, | 0x34, | 0x00, | 0x2D, | 0x2E,
3 | 0x02, | 0x21, | 0x2F, | 0x2E, | 0x36, | 0x37, | 0x38, | 0x06, | 0x19, | 0xFC, | 0xFD,
4 | 0x01, | 0x08, | 0x04, | 0x00, | 0x48, | 0x00, | 0x00, | 0x1B, | 0x46, | 0xFE, | 0xFF
FN2KEYS | 1 | 2 | 3 | 4 | 5 | 6 | 7 | 8 | 9 | 10 | 11
1 | 0x00, | 0x1E, | 0x1F, | 0x20, | 0x21, | 0x22, | 0x23, | 0x24, | 0x25, | 0x26, | 0x27,
2 | 0x53, | 0x64, | 0x37, | 0x64, | 0x23, | 0x2E, | 0x2E, | 0x31, | 0x34, | 0x2D, | 0x2E,
3 | 0x02, | 0x22, | 0x25, | 0x2D, | 0x1E, | 0x23, | 0x25, | 0x09, | 0x00, | 0xFC, | 0xFD,
4 | 0x01, | 0x08, | 0x04, | 0x00, | 0x00, | 0x1D, | 0x1A, | 0x15, | 0x1C, | 0xFE, | 0xFF
FN3KEYS | 1 | 2 | 3 | 4 | 5 | 6 | 7 | 8 | 9 | 10 | 11
1 | 0x00, | 0x3A, | 0x3B, | 0x3C, | 0x3D, | 0x3E, | 0x3F, | 0x40, | 0x41, | 0x42, | 0x43,
2 | 0x49, | 0x00, | 0x00, | 0x00, | 0x00, | 0x00, | 0x00, | 0x00, | 0x00, | 0x44, | 0x45,
3 | 0x02, | 0x00, | 0x00, | 0x00, | 0x00, | 0x00, | 0x00, | 0x00, | 0x00, | 0xFC, | 0xFD,
4 | 0x01, | 0x08, | 0x04, | 0x00, | 0x00, | 0x00, | 0x00, | 0x00, | 0x00, | 0xFE, | 0xFF
FN4KEYS | 1 | 2 | 3 | 4 | 5 | 6 | 7 | 8 | 9 | 10 | 11
1 | 0x00, | 0x35, | 0x1F, | 0x20, | 0x21, | 0x22, | 0x23, | 0x24, | 0x25, | 0x2F, | 0x27,
2 | 0x00, | 0x00, | 0x00, | 0x00, | 0x30, | 0x08, | 0x38, | 0x30, | 0x30, | 0x2D, | 0x2E,
3 | 0x02, | 0x00, | 0x00, | 0x00, | 0x00, | 0x87, | 0x31, | 0x4B, | 0x65, | 0xFC, | 0xFD,
4 | 0x01, | 0x08, | 0x04, | 0x00, | 0x00, | 0x00, | 0x4A, | 0x4E, | 0x4D, | 0xFE, | 0xFF
MODIFIER_MASK | 1 | 2 | 3 | 4 | 5 | 6 | 7 | 8 | 9 | 10 | 11
1 | 0, | 0, | 0, | 0, | 0, | 0, | 0, | 0, | 0, | 0, | 0,
2 | 0, | 0, | 0, | 0, | 0, | 0, | 0, | 0, | 0, | 0, | 0,
3 | 1, | 0, | 0, | 0, | 0, | 0, | 0, | 0, | 0, | 0, | 0,
4 | 1, | 1, | 1, | 0, | 0, | 0, | 0, | 0, | 0, | 0, | 0
TRIGGERS_MODIFIER | 1 | 2 | 3 | 4 | 5 | 6 | 7 | 8 | 9 | 10 | 11
1 | 0, | 4, | 132, | 132, | 132, | 132, | 132, | 132, | 132, | 4, | 132,
2 | 0, | 0, | 4, | 4, | 0, | 128, | 69, | 64, | 132, | 132, | 132,
3 | 0, | 10, | 9, | 10, | 1, | 8, | 64, | 6144, | 2048, | 0, | 0,
4 | 0, | 0, | 0, | 0, | 0, | 4096, | 4096, | 6144, | 4096, | 0, | 0
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

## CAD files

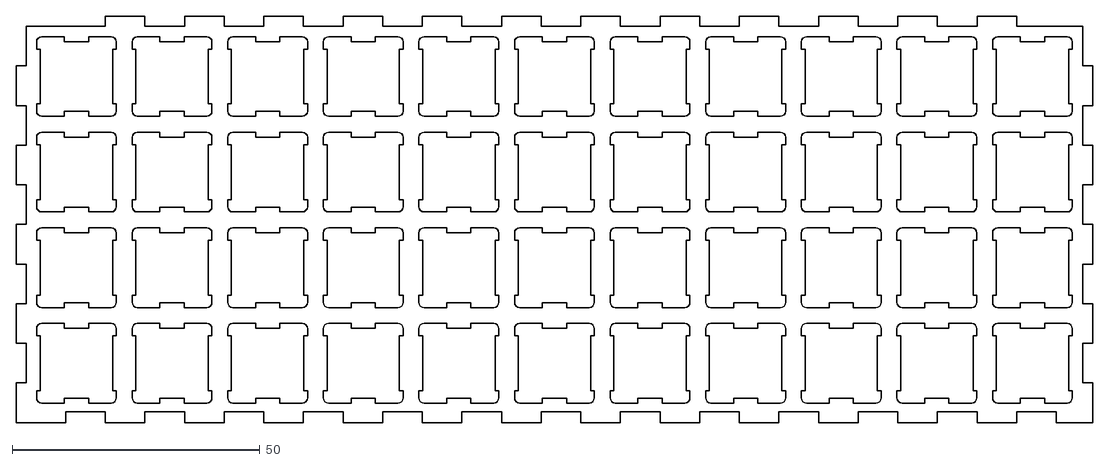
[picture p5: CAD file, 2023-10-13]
build/plaque_principale.DXF
217.4 x 82.0

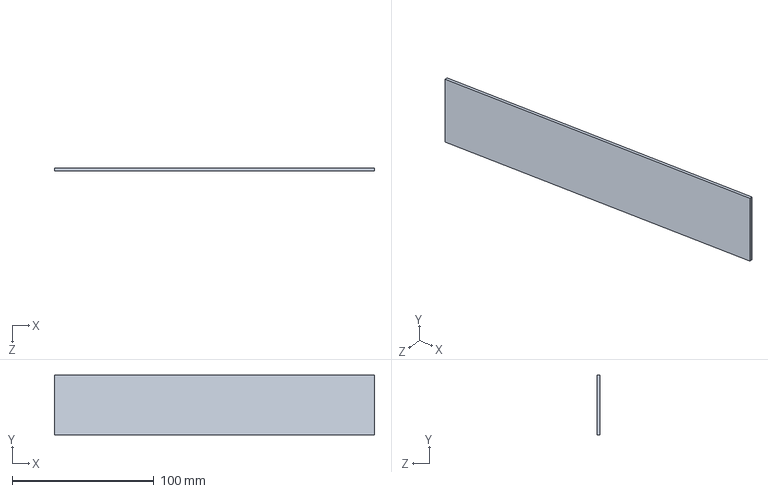
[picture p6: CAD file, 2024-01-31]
meca/plaque_frontale.SLDPRT
225.8 x 42.3 x 2.00 mm

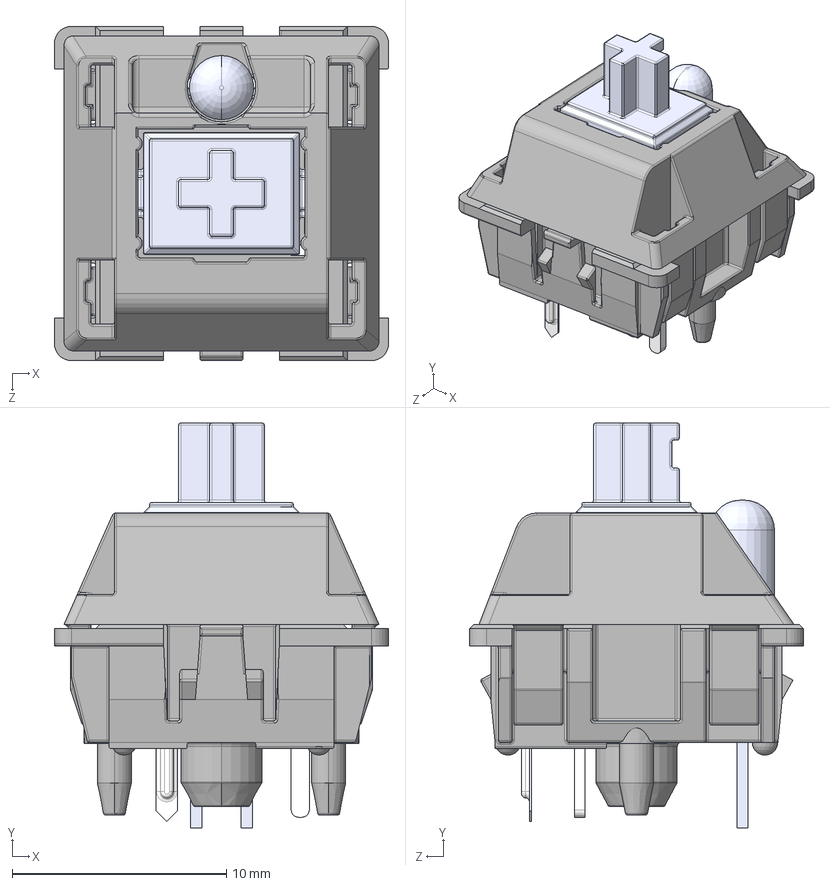
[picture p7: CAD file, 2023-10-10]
MX .STEP
15.6 x 18.9 x 15.6 mm
MX 轴 按键′_ü___¨1
MX 轴 轴体áì_¨￠¨__
MX粣 拸簽LEDLEDLED
MX轴 轴体 底部 μ×2__默认_á2____è_
针脚___默认__è_

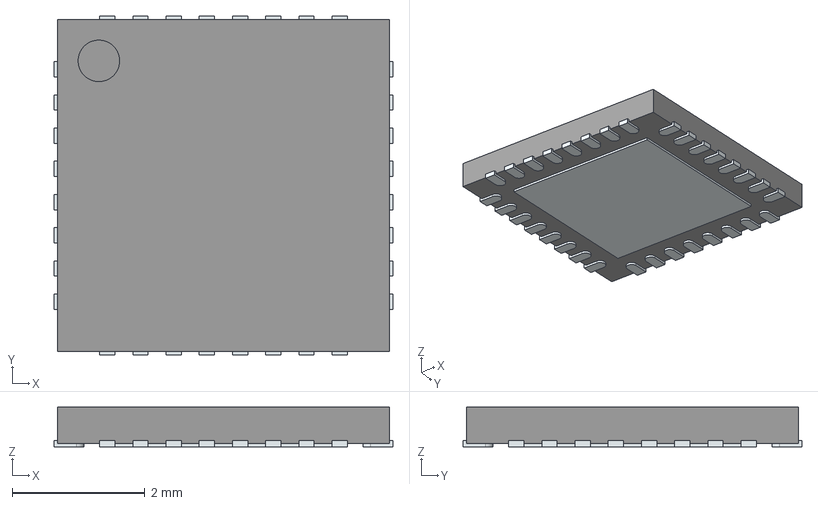
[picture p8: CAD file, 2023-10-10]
STM32L052K8U6TR/3D/STM32L052K8U6TR.stp
5.10 x 5.10 x 0.6 mm
ThermalPin
PinsArrayLR
PinsArrayTB

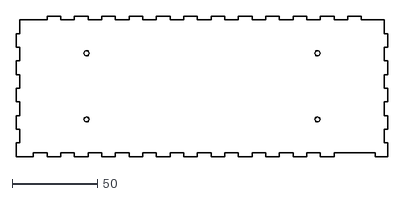
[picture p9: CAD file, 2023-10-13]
build/plaque_dessous.DXF
217.4 x 82.0

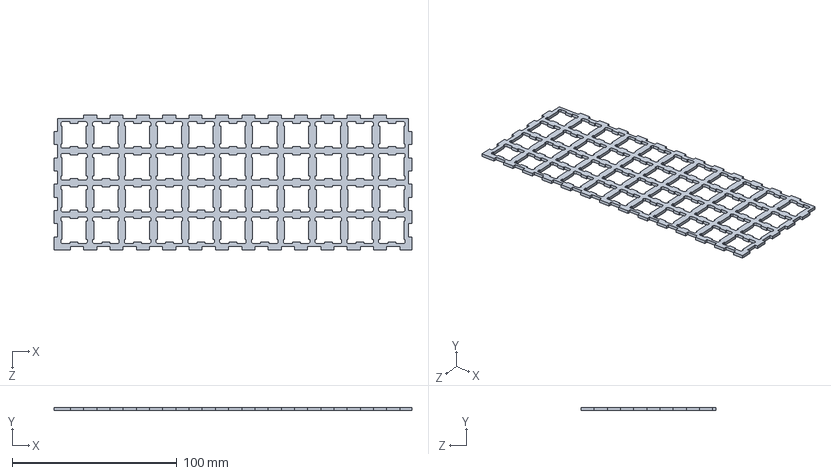
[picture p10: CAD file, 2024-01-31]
meca/plaque_principale.SLDPRT
217.4 x 2.00 x 82.0 mm

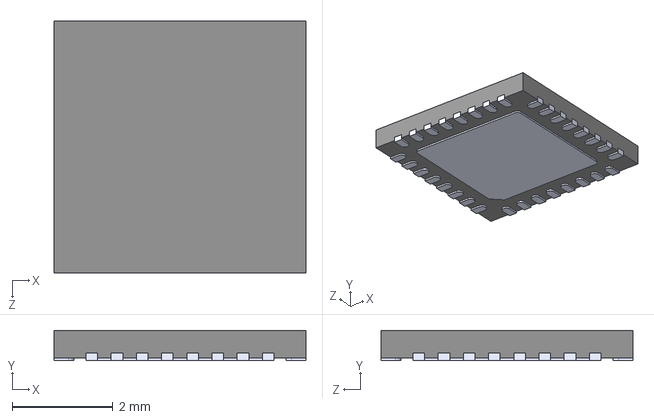
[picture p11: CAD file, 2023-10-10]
STM32L052K8U6TR.STEP
5.00 x 0.6 x 5.00 mm

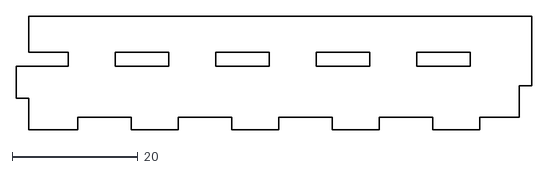
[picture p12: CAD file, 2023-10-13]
build/plaque_laterale.DXF
82.0 x 18.1

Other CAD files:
meca/MX.step.SLDASM
meca/SOT-353_SC-70-5.step.SLDASM
meca/R_0402_1005Metric.step.SLDASM
meca/C_0402_1005Metric.step.SLDASM
meca/TSOT-23-6.step.SLDASM
meca/mxcap.step.SLDASM
meca/C_0805_2012Metric.step.SLDASM
meca/D_SOD-323.step.SLDASM
meca/R_0805_2012Metric.step.SLDASM
meca/PinHeader_1x04_P2.54mm_Vertical.step.SLDASM
2130830005.stp
build/plaque_arriere.DXF
build/plaque_frontale.DXF
meca/2130830005.step.SLDASM
meca/COMPOUND-2.step.SLDPRT
meca/M3x10.SLDPRT
meca/USB-C and flexed cable.step
meca/ecrou_M3.SLDPRT
meca/entretoise.SLDPRT
meca/keyboard_steamdeck PCB.step.SLDPRT
meca/plaque_arriere.DXF
meca/plaque_arriere.SLDPRT
meca/plaque_frontale.DXF
meca/plaque_laterale.DXF
meca/plaque_laterale.SLDPRT
meca/plaque_principale.DXF
meca/plaque_principale_pleine.DXF
meca/separator.SLDPRT
mxcap.STEP

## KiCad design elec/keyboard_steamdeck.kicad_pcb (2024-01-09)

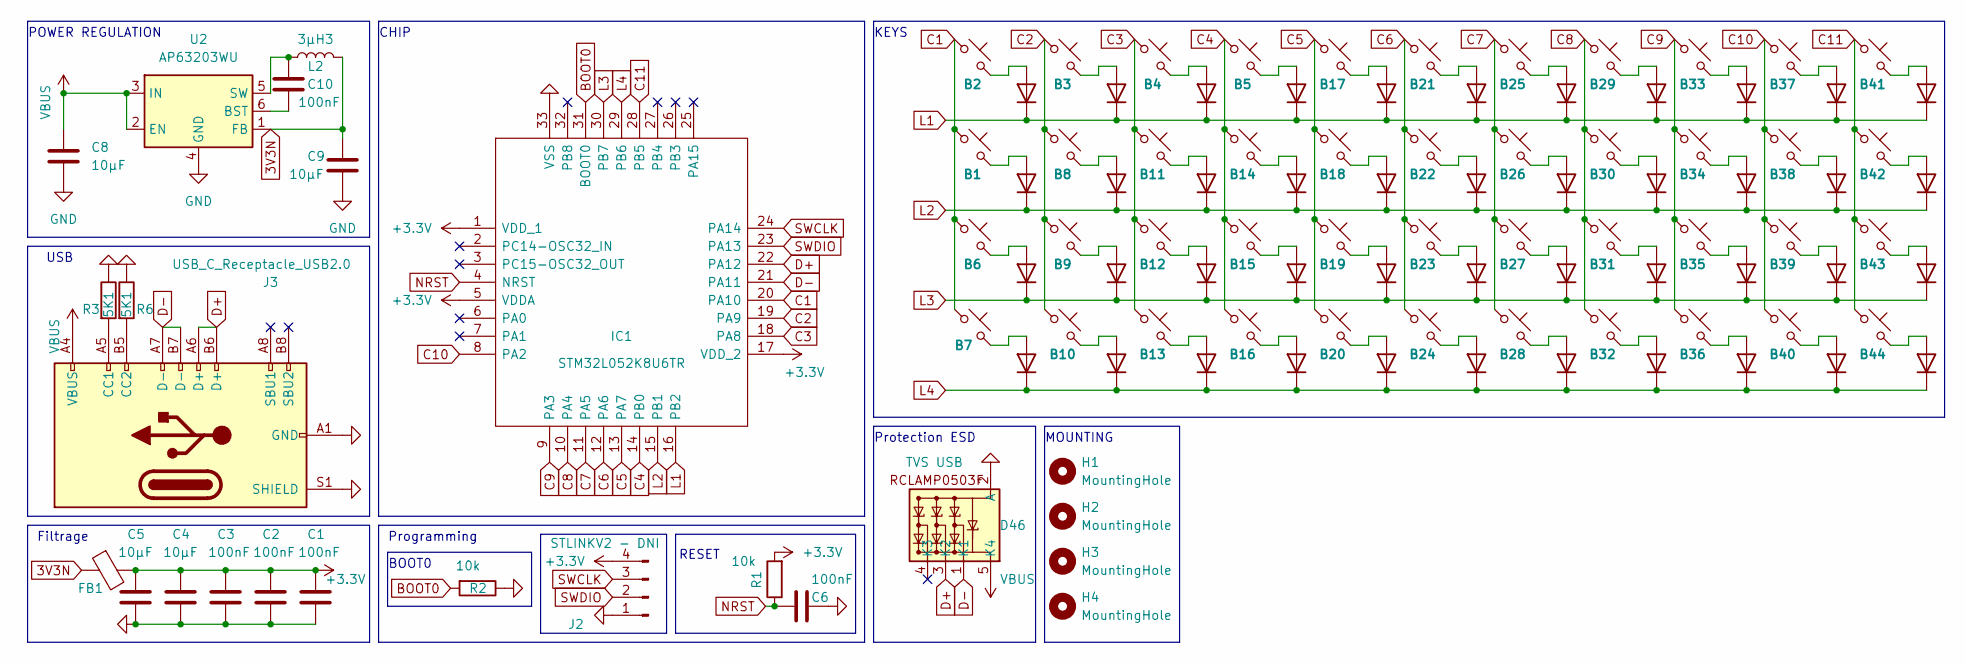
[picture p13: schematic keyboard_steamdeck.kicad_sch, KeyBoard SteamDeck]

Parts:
B1, B2, B3, B4, B5, B6, B7, B8, B9, B10, B11, B12, B13, B14, B15, B16, B17, B18, B19, B20, B21, B22, B23, B24, B25, B26, B27, B28, B29, B30, B31, B32, B33, B34, B35, B36, B37, B38, B39, B40, B41, B42, B43, B44: MX_SW_solder - DNI; SW_Cherry_MX_1.00u_PCB; MPN MX2A-L1NN
C1, C2, C3, C6, C10: 100nF; C_0402_1005Metric; MPN CC0402KRX7R8BB104
C4, C5, C8, C9: 10µF; C_0805_2012Metric; MPN CAP0805 X7R 10UF 10% 16V
D1, D2, D3, D4, D5, D6, D7, D8, D9, D10, D11, D12, D13, D14, D15, D16, D17, D18, D19, D20, D21, D22, D23, D24, D25, D26, D27, D28, D29, D30, D31, D32, D33, D34, D35, D36, D37, D38, D39, D40, D41, D42, D43, D44: 1N4148WX-TP; D_SOD-323_HandSoldering; MPN 1N4148WX-TP
D46: TVS USB; SOT-353_SC-70-5; MPN RCLAMP0503F.TCT
FB1: FerriteBead; R_0402_1005Metric; MPN PE-0603PFB121ST
H1, H2, H3, H4: MountingHole; MountingHole_3.2mm_M3
IC1: STM32L052K8U6TR; UFQFPN32-5x5mm; MPN STM32L052K8U6TR
J2: STLINKV2 - DNI; PinHeader_1x04_P2.54mm_Vertical; MPN 61300411121
J3: USB_C_Receptacle_USB2.0; USB C 2130830005; MPN 2130830005
L2: 3µH3; R_0805_2012Metric; MPN MLZ2012N3R3LT000
R1, R2: 10k; R_0402_1005Metric; MPN ERA-2AEB103X
R3, R6: 5K1; R_0402_1005Metric; MPN RN73R1ETTP5101B25
U2: AP63203WU; TSOT-23-6; MPN AP63203WU-7

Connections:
3V3N: C9.1, FB1.1, L2.2, U2.1 (FB)
+3.3V: C1.2, C2.2, C3.2, C4.2, C5.2, FB1.2, IC1.1 (VDD_1), IC1.5 (VDDA), IC1.17 (VDD_2), J2.4, R1.2
BOOT0: IC1.31 (BOOT0), R2.2
C1: B1.1, B2.1, B6.1, B7.1, IC1.20 (PA10)
C2: B3.1, B8.1, B9.1, B10.1, IC1.19 (PA9)
C3: B4.1, B11.1, B12.1, B13.1, IC1.18 (PA8)
C4: B5.1, B14.1, B15.1, B16.1, IC1.14 (PB0)
C5: B17.1, B18.1, B19.1, B20.1, IC1.13 (PA7)
C6: B21.1, B22.1, B23.1, B24.1, IC1.12 (PA6)
C7: B25.1, B26.1, B27.1, B28.1, IC1.11 (PA5)
C8: B29.1, B30.1, B31.1, B32.1, IC1.10 (PA4)
C9: B33.1, B34.1, B35.1, B36.1, IC1.9 (PA3)
C10: B37.1, B38.1, B39.1, B40.1, IC1.8 (PA2)
C11: B41.1, B42.1, B43.1, B44.1, IC1.28 (PB5)
D+: D46.3 (K2), IC1.22 (PA12), J3.A6 (D+), J3.B6 (D+)
D-: D46.1 (K1), IC1.21 (PA11), J3.A7 (D-), J3.B7 (D-)
GND: C1.1, C2.1, C3.1, C4.1, C5.1, C6.1, C8.2, C9.2, D46.2 (A), IC1.33 (VSS), J2.1, J3.A1 (GND), J3.A12 (GND), J3.B1 (GND), J3.B12 (GND), J3.S1 (SHIELD), R2.1, R3.1, R6.1, U2.4 (GND)
L1: D11.1 (K), D12.1 (K), D13.1 (K), D14.1 (K), D15.1 (K), D16.1 (K), D17.1 (K), D18.1 (K), D19.1 (K), D20.1 (K), D41.1 (K), IC1.16 (PB2)
L2: D1.1 (K), D2.1 (K), D3.1 (K), D4.1 (K), D5.1 (K), D6.1 (K), D7.1 (K), D8.1 (K), D9.1 (K), D10.1 (K), D42.1 (K), IC1.15 (PB1)
L3: D21.1 (K), D23.1 (K), D25.1 (K), D27.1 (K), D29.1 (K), D31.1 (K), D33.1 (K), D35.1 (K), D37.1 (K), D39.1 (K), D43.1 (K), IC1.30 (PB7)
L4: D22.1 (K), D24.1 (K), D26.1 (K), D28.1 (K), D30.1 (K), D32.1 (K), D34.1 (K), D36.1 (K), D38.1 (K), D40.1 (K), D44.1 (K), IC1.29 (PB6)
NRST: C6.2, IC1.4 (NRST), R1.1
unnamed: B22.2, D1.2 (A)
unnamed: B26.2, D2.2 (A)
unnamed: B30.2, D3.2 (A)
unnamed: B34.2, D4.2 (A)
unnamed: B38.2, D5.2 (A)
unnamed: B1.2, D6.2 (A)
unnamed: B8.2, D7.2 (A)
unnamed: B11.2, D8.2 (A)
unnamed: B14.2, D9.2 (A)
unnamed: B18.2, D10.2 (A)
unnamed: B2.2, D11.2 (A)
unnamed: B3.2, D12.2 (A)
unnamed: B4.2, D13.2 (A)
unnamed: B5.2, D14.2 (A)
unnamed: B17.2, D15.2 (A)
unnamed: B21.2, D16.2 (A)
unnamed: B25.2, D17.2 (A)
unnamed: B29.2, D18.2 (A)
unnamed: B33.2, D19.2 (A)
unnamed: B37.2, D20.2 (A)
unnamed: B6.2, D21.2 (A)
unnamed: B7.2, D22.2 (A)
unnamed: B9.2, D23.2 (A)
unnamed: B10.2, D24.2 (A)
unnamed: B12.2, D25.2 (A)
unnamed: B13.2, D26.2 (A)
unnamed: B15.2, D27.2 (A)
unnamed: B16.2, D28.2 (A)
unnamed: B19.2, D29.2 (A)
unnamed: B20.2, D30.2 (A)
unnamed: B23.2, D31.2 (A)
unnamed: B24.2, D32.2 (A)
unnamed: B27.2, D33.2 (A)
unnamed: B28.2, D34.2 (A)
unnamed: B31.2, D35.2 (A)
unnamed: B32.2, D36.2 (A)
unnamed: B35.2, D37.2 (A)
unnamed: B36.2, D38.2 (A)
unnamed: B39.2, D39.2 (A)
unnamed: B40.2, D40.2 (A)
unnamed: B41.2, D41.2 (A)
unnamed: B42.2, D42.2 (A)
unnamed: B43.2, D43.2 (A)
unnamed: B44.2, D44.2 (A)
unnamed: J3.A5 (CC1), R3.2
unnamed: J3.B5 (CC2), R6.2
unnamed: C10.2, U2.6 (BST)
unnamed: C10.1, L2.1, U2.5 (SW)
SWCLK: IC1.24 (PA14), J2.3
SWDIO: IC1.23 (PA13), J2.2
VBUS: C8.1, D46.5 (K4), J3.A4 (VBUS), J3.A9 (VBUS), J3.B4 (VBUS), J3.B9 (VBUS), U2.2 (EN), U2.3 (IN)

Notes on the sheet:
CHIP
Filtrage
KEYS
MOUNTING
POWER REGULATION
RESET
BOOT0
Protection ESD
USB
Programming

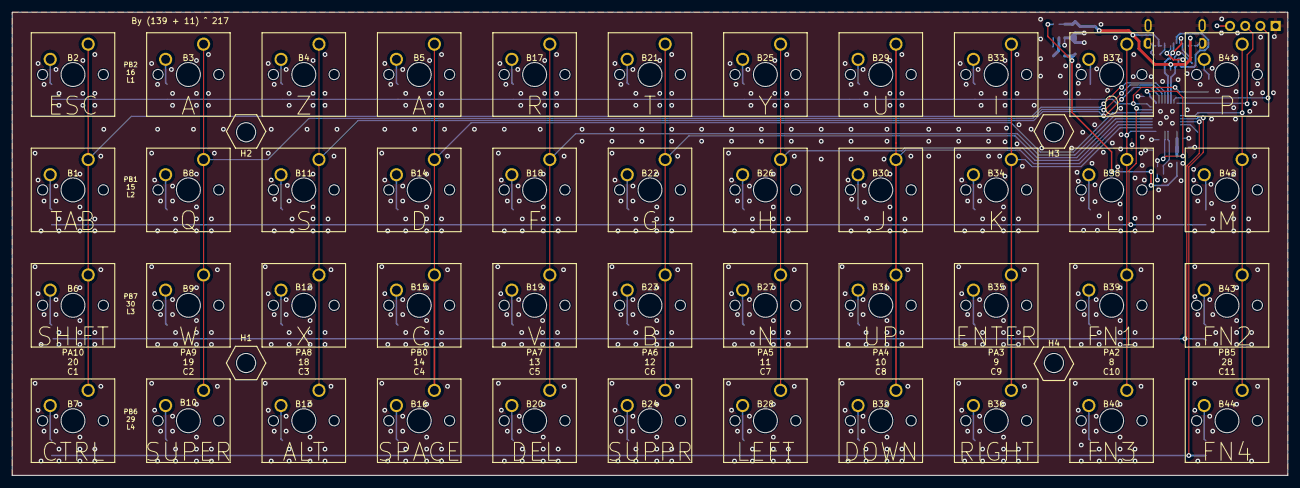
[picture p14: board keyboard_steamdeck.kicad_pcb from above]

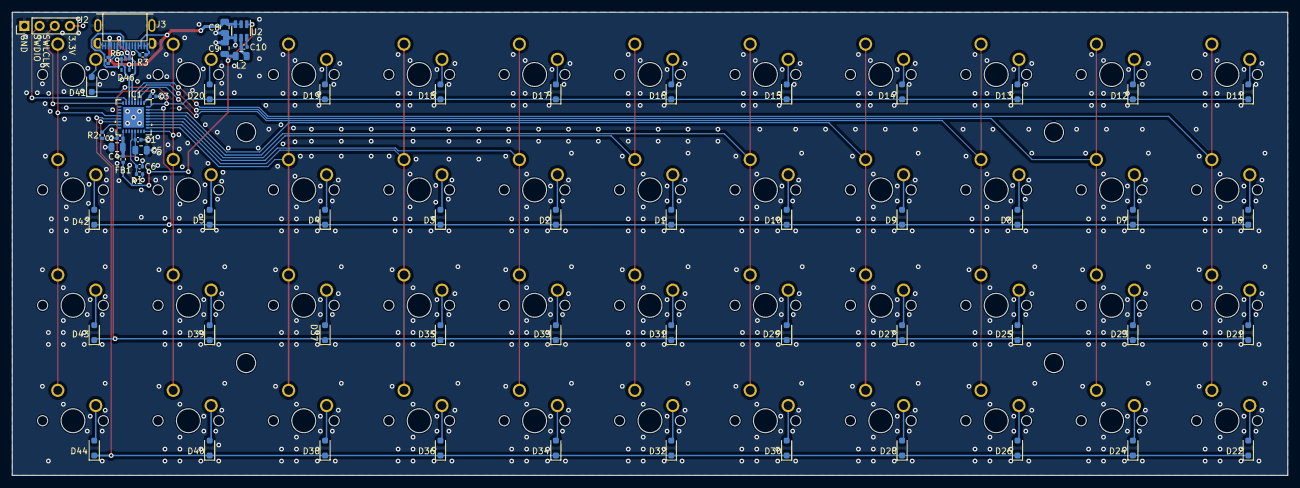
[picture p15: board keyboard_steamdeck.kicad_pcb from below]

Board: 4 copper layers, 213.4 x 77.5 mm, 112 parts (64 on the bottom side), 73 nets.

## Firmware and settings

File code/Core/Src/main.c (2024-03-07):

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
/* Includes ------------------------------------------------------------------*/
#include "main.h"
#include "usb_device.h"

/* USER CODE BEGIN Includes */
#include "usbd_hid.h"
#include <stdbool.h>
/* USER CODE END Includes */

/* USER CODE BEGIN PD */
#define KEY_MOD_RCTRL 	0x10
#define KEY_MOD_RSHIFT 	0x20
#define KEY_MOD_RALT   	0x40
#define KEY_NONE 		0x00
#define KEY_ERR_OVF 	0x01

#define INDEX_FN1		31
#define INDEX_FN2		32
#define INDEX_FN3		42
#define INDEX_FN4		43


#define NUM_FN4_CTRL	16384
#define NUM_FN3_CTRL	8192
#define NUM_FN2_CTRL	4096
#define NUM_FN1_CTRL	2048
#define NUM_KEY_CTRL	1024
#define NUM_KEY_ALTGR	512
#define NUM_KEY_SHIFT	256
#define NUM_FN4_ALTGR	128
#define NUM_FN4_SHIFT	64
#define NUM_FN3_ALTGR	32
#define NUM_FN3_SHIFT	16
#define NUM_FN2_ALTGR	8
#define NUM_FN2_SHIFT	4
#define NUM_FN1_ALTGR	2
#define NUM_FN1_SHIFT	1
/* USER CODE END PD */


/* USER CODE BEGIN PV */
extern USBD_HandleTypeDef hUsbDeviceFS;
typedef struct{
	uint8_t MODIFIER;
	uint8_t RESERVED;
	uint8_t KEYCODE1;
	uint8_t KEYCODE2;
	uint8_t KEYCODE3;
	uint8_t KEYCODE4;
	uint8_t KEYCODE5;
	uint8_t KEYCODE6;
}subKeyBoard;
subKeyBoard keyBoardHIDsub = {0, 0, 0, 0, 0, 0, 0, 0};
/* USER CODE END PV */

void SystemClock_Config(void);
static void MX_GPIO_Init(void);
/* USER CODE BEGIN PFP */

uint8_t INPUTKEYS[44] = {
		0x29,	0x14,	0x1A,	0x08,	0x15,	0x17,	0x1C,	0x18,	0x0C,	0x12,	0x13,
		0x2B,	0x04,	0x16,	0x07,	0x09,	0x0A,	0x0B,	0x0D,	0x0E,	0x0F,	0x33,
		0x02,	0x1D,	0x1B,	0x06,	0x19,	0x05,	0x11,	0x52,	0x28,	0xFC,	0xFD,
		0x01,	0x08,	0x04,	0x2C,	0x2A,	0x4C,	0x50,	0x51,	0x4F,	0xFE,	0xFF
};
uint8_t FN1KEYS[44] = {
		0x00,	0x1E,	0x1F,	0x20,	0x21,	0x22,	0x23,	0x24,	0x25,	0x26,	0x27,
		0x39,	0x22,	0x00,	0x2D,	0x00,	0x00,	0x00,	0x00,	0x00,	0x2D,	0x2E,
		0x02,	0x10,	0x36,	0x10,	0x36,	0x37,	0x38,	0x4B,	0x06,	0xFC,	0xFD,
		0x01,	0x08,	0x04,	0x23,	0x1A,	0x1C,	0x4A,	0x4E,	0x4D,	0xFE,	0xFF
};
uint8_t FN2KEYS[44] = {
		0x00,	0x1E,	0x1F,	0x20,	0x21,	0x22,	0x23,	0x24,	0x25,	0x26,	0x27,
		0x53,	0x22,	0x08,	0x2D,	0x00,	0x00,	0x00,	0x00,	0x00,	0x2D,	0x2E,
		0x02,	0x00,	0x00,	0x00,	0x00,	0x00,	0x00,	0x09,	0x1B,	0xFC,	0xFD,
		0x01,	0x08,	0x04,	0x25,	0x00,	0x00,	0x00,	0x15,	0x00,	0xFE,	0xFF
};
uint8_t FN3KEYS[44] = {
		0x00,	0x3A,	0x3B,	0x3C,	0x3D,	0x3E,	0x3F,	0x40,	0x41,	0x42,	0x43,
		0x49,	0x21,	0x08,	0x2E,	0x00,	0x00,	0x34,	0x2F,	0x30,	0x44,	0x45,
		0x02,	0x08,	0x38,	0x30,	0x30,	0x34,	0x31,	0x00,	0x19,	0xFC,	0xFD,
		0x01,	0x08,	0x04,	0x00,	0x00,	0x00,	0x00,	0x48,	0x00,	0xFE,	0xFF
};
uint8_t FN4KEYS[44] = {
		0x00,	0x35,	0x1F,	0x20,	0x21,	0x22,	0x23,	0x24,	0x25,	0x2F,	0x27,
		0x00,	0x64,	0x2F,	0x64,	0x00,	0x00,	0x00,	0x00,	0x00,	0x2D,	0x2E,
		0x02,	0x00,	0x00,	0x00,	0x00,	0x00,	0x00,	0x00,	0x46,	0xFC,	0xFD,
		0x01,	0x08,	0x04,	0x00,	0x00,	0x00,	0x00,	0x00,	0x65,	0xFE,	0xFF
};
bool MODIFIER_MASK[44] = {  // Mask of hardware fixed modifier keys (SHIFT, ALT, SUPER, CTRL)
		false, 	false, 	false, 	false, 	false, 	false, 	false, 	false, 	false, 	false, 	false,
		false, 	false, 	false, 	false, 	false, 	false, 	false, 	false, 	false, 	false, 	false,
		true, 	false, 	false, 	false, 	false, 	false, 	false, 	false, 	false, 	false, 	false,
		true, 	true, 	true, 	false, 	false, 	false, 	false, 	false, 	false, 	false, 	false
};
uint16_t TRIGGERS_MODIFIER[44] = {  // Mask for FN1-shift(1)FN1-altgr(2)FN2-shift(4)FN2-altgr(8)FN3-shift(16)FN3-altgr(32)FN4-shift(64)FN4-altgr(128)KEY-shift(256)Key-altgr(512)
		0,	4,	132,	132,	132,	132,	132,	132,	132,	4,	132,
		0,	40,	0,	104,	0,	0,	16,	16,	32,	132,	132,
		0,	33,	17,	16,	0,	0,	16,	4096,	14336,	0,	0,
		0,	0,	0,	0,	2048,	2048,	0,	0,	0,	0,	0
};
GPIO_TypeDef *GPIOPORTS_C[11] = {	GPIOA, 			GPIOA, 			GPIOA, 			GPIOB, 			GPIOA, 			GPIOA, 			GPIOA, 			GPIOA, 			GPIOA, 			GPIOA, 			GPIOB		};
int PINS_C[11] = {					GPIO_PIN_10, 	GPIO_PIN_9, 	GPIO_PIN_8, 	GPIO_PIN_0, 	GPIO_PIN_7, 	GPIO_PIN_6, 	GPIO_PIN_5, 	GPIO_PIN_4, 	GPIO_PIN_3, 	GPIO_PIN_2, 	GPIO_PIN_5	};
GPIO_TypeDef *GPIOPORTS_L[4] = {	GPIOB, 			GPIOB, 			GPIOB, 			GPIOB};
int PINS_L[4] = {					GPIO_PIN_2, 	GPIO_PIN_1, 	GPIO_PIN_7, 	GPIO_PIN_6};
/* USER CODE END PFP */

/**
  * @brief  The application entry point.
  * @retval int
  */
int main(void)
{
  /* MCU Configuration--------------------------------------------------------*/

  /* Reset of all peripherals, Initializes the Flash interface and the Systick. */
  HAL_Init();

  /* Configure the system clock */
  SystemClock_Config();

  /* Initialize all configured peripherals */
  MX_GPIO_Init();
  MX_USB_DEVICE_Init();
  /* Infinite loop */
  /* USER CODE BEGIN WHILE */
  bool last_pressed = false;
  while (1){
    /* USER CODE END WHILE */

    /* USER CODE BEGIN 3 */
	  bool PRESSED[44] = {  // Initialize physical mask pressed keys to all false
		false, 	false, 	false, 	false, 	false, 	false, 	false, 	false, 	false, 	false, 	false,
		false, 	false, 	false, 	false, 	false, 	false, 	false, 	false, 	false, 	false, 	false,
		false, 	false, 	false, 	false, 	false, 	false, 	false, 	false, 	false, 	false, 	false,
		false, 	false, 	false, 	false, 	false, 	false, 	false, 	false, 	false, 	false, 	false
	  };
	  bool press = false;  // Initialize pressed any physical key on keyboard
	  bool press_fn_bar = false;  // Initialize pressed any physical key that are not FN key
	  for (int c=0; c<11; c++) HAL_GPIO_WritePin(GPIOPORTS_C[c], PINS_C[c], GPIO_PIN_SET);  // All columns GPIO are turned ON
	  for (int line=0; line<4; line++) {
		  if(HAL_GPIO_ReadPin (GPIOPORTS_L[line], PINS_L[line])){  // Lines GPIO are checked
			  press = true;  // If one or more line GPIO are true: a key has been pressed
			  line = 4;
		   }
	  }

	  if (press){
		  for (int c=0; c<11; c++) HAL_GPIO_WritePin(GPIOPORTS_C[c], PINS_C[c], GPIO_PIN_RESET);  // All columns GPIO are turned OFF
		  for (int line=0; line<4; line++) {
			  for (int c=0; c<11; c++){  // Scan columns one by one to get all keys
				  HAL_GPIO_WritePin(GPIOPORTS_C[c], PINS_C[c], GPIO_PIN_SET);  // Turn ON GPIO of scanned column
				  if(HAL_GPIO_ReadPin (GPIOPORTS_L[line], PINS_L[line])){  // Check again line GPIO to test (column x line)
					  PRESSED[line * 11 + c] = true;  // Index of physical pressed key is turned to true
				  }
				  HAL_GPIO_WritePin(GPIOPORTS_C[c], PINS_C[c], GPIO_PIN_RESET);  // Turn OFF GPIO of scanned column
			  }
		  }

		  bool fn1 = PRESSED[INDEX_FN1];  // Check if FN1 is pressed
		  bool fn2 = PRESSED[INDEX_FN2];  // Check if FN2 is pressed
		  bool fn3 = PRESSED[INDEX_FN3];  // Check if FN3 is pressed
		  bool fn4 = PRESSED[INDEX_FN4];  // Check if FN4 is pressed

		  keyBoardHIDsub.MODIFIER = KEY_NONE;
		  keyBoardHIDsub.KEYCODE1 = KEY_NONE;
		  keyBoardHIDsub.KEYCODE2 = KEY_NONE;
		  keyBoardHIDsub.KEYCODE3 = KEY_NONE;
		  keyBoardHIDsub.KEYCODE4 = KEY_NONE;
		  keyBoardHIDsub.KEYCODE5 = KEY_NONE;
		  keyBoardHIDsub.KEYCODE6 = KEY_NONE;

		  for (int index=0; index<44; index++) {  // Loop on every physical keys
			  if (
				  !PRESSED[index] ||  // Physical key is not pressed
				  //MODIFIER_MASK[index] ||  // Si touches de modifier pressed
				  index == INDEX_FN1 ||  // FN1 is not analyzed
				  index == INDEX_FN2 ||  // FN2 is not analyzed
				  index == INDEX_FN3 ||  // FN3 is not analyzed
				  index == INDEX_FN4     // FN4 is not analyzed
			  ) continue;

			  press_fn_bar = true;  // A key that is not FN has been pressed

			  uint8_t 		  key = (uint8_t)INPUTKEYS[index];  // Affect standard key
			  if 		(fn1) key = (uint8_t)FN1KEYS[index];  // Affect FN1 key if is pressed
			  else if 	(fn2) key = (uint8_t)FN2KEYS[index];  // Affect FN2 key if is pressed€
			  else if 	(fn3) key = (uint8_t)FN3KEYS[index];  // Affect FN3 key if is pressed
			  else if 	(fn4) key = (uint8_t)FN4KEYS[index];  // Affect FN4 key if is pressed

			  uint16_t trigger_modifier = (uint16_t)TRIGGERS_MODIFIER[index];  // Get Modifier value index
			  // Affect modifier if specified in table TRIGGERS_MODIFIER
			  bool fn4_ctrl = trigger_modifier >= NUM_FN4_CTRL;
			  trigger_modifier -= NUM_FN4_CTRL * fn4_ctrl;
			  bool fn3_ctrl = trigger_modifier >= NUM_FN3_CTRL;
			  trigger_modifier -= NUM_FN3_CTRL * fn3_ctrl;
			  bool fn2_ctrl = trigger_modifier >= NUM_FN2_CTRL;
			  trigger_modifier -= NUM_FN2_CTRL * fn2_ctrl;
			  bool fn1_ctrl = trigger_modifier >= NUM_FN1_CTRL;
			  trigger_modifier -= NUM_FN1_CTRL * fn1_ctrl;
			  bool key_ctrl = trigger_modifier >= NUM_KEY_CTRL;
			  trigger_modifier -= NUM_KEY_CTRL * key_ctrl;
			  bool key_altgr = trigger_modifier >= NUM_KEY_ALTGR;  // If value in TRIGGERS_MODIFIER is higher than NUM_KEY_ALTGR
			  trigger_modifier -= NUM_KEY_ALTGR * key_altgr;  // Remove value NUM_KEY€_ALTGR from TRIGGERS_MODIFIER value index of key
			  bool key_shift = trigger_modifier >= NUM_KEY_SHIFT;  // Repeat for NUM_KEY_SHIFT
			  trigger_modifier -= NUM_KEY_SHIFT * key_shift;  // Repeat for NUM_KEY_SHIFT
			  bool fn4_altgr = trigger_modifier >= NUM_FN4_ALTGR;
			  trigger_modifier -= NUM_FN4_ALTGR * fn4_altgr;
			  bool fn4_shift = trigger_modifier >= NUM_FN4_SHIFT;
			  trigger_modifier -= NUM_FN4_SHIFT * fn4_shift;
			  bool fn3_altgr = trigger_modifier >= NUM_FN3_ALTGR;
			  trigger_modifier -= NUM_FN3_ALTGR * fn3_altgr;
			  bool fn3_shift = trigger_modifier >= NUM_FN3_SHIFT;
			  trigger_modifier -= NUM_FN3_SHIFT * fn3_shift;
			  bool fn2_altgr = trigger_modifier >= NUM_FN2_ALTGR;
			  trigger_modifier -= NUM_FN2_ALTGR * fn2_altgr;
			  bool fn2_shift = trigger_modifier >= NUM_FN2_SHIFT;
			  trigger_modifier -= NUM_FN2_SHIFT * fn2_shift;
			  bool fn1_altgr = trigger_modifier >= NUM_FN1_ALTGR;
			  trigger_modifier -= NUM_FN1_ALTGR * fn1_altgr;
			  bool fn1_shift = trigger_modifier >= NUM_FN1_SHIFT;
			  trigger_modifier -= NUM_FN1_SHIFT * fn1_shift;

			  if (
				  (key_altgr && !(fn1 || fn2 || fn3 || fn4)) ||
				  (fn4_altgr && fn4) ||
				  (fn3_altgr && fn3) ||
				  (fn2_altgr && fn2) ||
				  (fn1_altgr && fn1)
			  ) keyBoardHIDsub.MODIFIER |= KEY_MOD_RALT;

			  else if (
				  (key_shift && !(fn1 || fn2 || fn3 || fn4)) ||
				  (fn4_shift && fn4)  ||
				  (fn3_shift && fn3)  ||
				  (fn2_shift && fn2)  ||
				  (fn1_shift && fn1)
			  ) keyBoardHIDsub.MODIFIER |= KEY_MOD_RSHIFT;

			  else if (
				  (key_ctrl && !(fn1 || fn2 || fn3 || fn4)) ||
				  (fn4_ctrl && fn4)  ||
				  (fn3_ctrl && fn3)  ||
				  (fn2_ctrl && fn2)  ||
				  (fn1_ctrl && fn1)
			  ) keyBoardHIDsub.MODIFIER |= KEY_MOD_RCTRL;

			  if (MODIFIER_MASK[index] && PRESSED[index]) 	keyBoardHIDsub.MODIFIER |= 	key;
			  else if 	(keyBoardHIDsub.KEYCODE1 == 0x00) 	keyBoardHIDsub.KEYCODE1 = 	key;
			  else if 	(keyBoardHIDsub.KEYCODE2 == 0x00) 	keyBoardHIDsub.KEYCODE2 = 	key;
			  else if 	(keyBoardHIDsub.KEYCODE3 == 0x00) 	keyBoardHIDsub.KEYCODE3 = 	key;
			  else if 	(keyBoardHIDsub.KEYCODE4 == 0x00) 	keyBoardHIDsub.KEYCODE4 = 	key;
			  else if 	(keyBoardHIDsub.KEYCODE5 == 0x00) 	keyBoardHIDsub.KEYCODE5 = 	key;
			  else if 	(keyBoardHIDsub.KEYCODE6 == 0x00) 	keyBoardHIDsub.KEYCODE6 = 	key;
			  else {  // Too much key pressed
				  keyBoardHIDsub.MODIFIER = KEY_ERR_OVF;
				  keyBoardHIDsub.KEYCODE1 = KEY_ERR_OVF;
				  keyBoardHIDsub.KEYCODE2 = KEY_ERR_OVF;
				  keyBoardHIDsub.KEYCODE3 = KEY_ERR_OVF;
				  keyBoardHIDsub.KEYCODE4 = KEY_ERR_OVF;
				  keyBoardHIDsub.KEYCODE5 = KEY_ERR_OVF;
				  keyBoardHIDsub.KEYCODE6 = KEY_ERR_OVF;
			  }
		  };
		  if (press_fn_bar){
			  USBD_HID_SendReport(&hUsbDeviceFS, &keyBoardHIDsub, sizeof(keyBoardHIDsub));  // Send keys report thought USB
		  }
	  }

	  if (!press_fn_bar && last_pressed) {
		  keyBoardHIDsub.MODIFIER = KEY_NONE;
		  keyBoardHIDsub.KEYCODE1 = KEY_NONE;
		  keyBoardHIDsub.KEYCODE2 = KEY_NONE;
		  keyBoardHIDsub.KEYCODE3 = KEY_NONE;
		  keyBoardHIDsub.KEYCODE4 = KEY_NONE;
		  keyBoardHIDsub.KEYCODE5 = KEY_NONE;
		  keyBoardHIDsub.KEYCODE6 = KEY_NONE;
		  USBD_HID_SendReport(&hUsbDeviceFS, &keyBoardHIDsub, sizeof(keyBoardHIDsub));
	  }
	  last_pressed = press_fn_bar;
	  HAL_Delay(50);  // Wait of loop iteration in ms
  }
  /* USER CODE END 3 */
}

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


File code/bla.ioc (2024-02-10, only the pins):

Mcu.UserName=STM32L052K8Ux
PA10.Signal=GPIO_Output
PA11.Signal=USB_DM
PA12.Signal=USB_DP
PA13.Signal=SYS_SWDIO
PA14.Signal=SYS_SWCLK
PA2.Signal=GPIO_Output
PA3.Signal=GPIO_Output
PA4.Signal=GPIO_Output
PA5.Signal=GPIO_Output
PA6.Signal=GPIO_Output
PA7.Signal=GPIO_Output
PA8.Signal=GPIO_Output
PA9.Signal=GPIO_Output
PB0.Signal=GPIO_Output
PB1.Signal=GPIO_Input
PB2.Signal=GPIO_Input
PB5.Signal=GPIO_Output
PB6.Signal=GPIO_Input
PB7.Signal=GPIO_Input

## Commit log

2023-10-13 ready to order PCB
    [BOM.xlsx, BOM_electronic.xlsx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]
2024-02-10 fix FN infinite repeat
    [bla.ioc, main.c]
2024-02-19 almost working firmaware
    [touches liste.xlsx]
2024-02-19 WIP still some bugs
    [touches liste.xlsx]
2024-02-23 working keyboard
    [touches liste.xlsx]
